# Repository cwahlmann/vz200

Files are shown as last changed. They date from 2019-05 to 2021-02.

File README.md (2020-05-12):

# VZ200
## Nachbau eines VZ200-Color-Computers (1983)

Mit einem funktionstüchtigen Nachbau des "VZ200 Color Computer" von 1983 lassen wir die Welt der 8-Bit Computer wieder auferstehen.

__Autoren:__ Jürgen Wahlmann & Christian Wahlmann



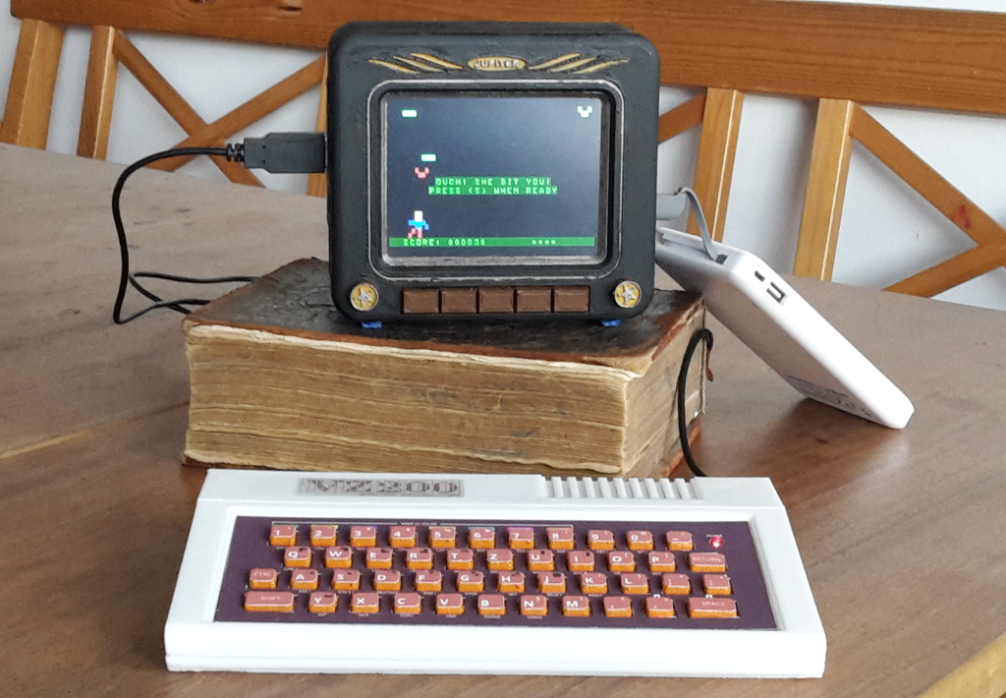
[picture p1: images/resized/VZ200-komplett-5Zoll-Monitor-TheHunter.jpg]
Prototyp VZ200 - 70%


Dieses Repository dient der Verwaltung aller Sourcen, insbesondere
* 3d-Modelle (Fusion360)
* Platinenlayout (KiCad)
* Grafiken für Tastatur- und Logo-Aufkleber
* JemuVZ200-Emulator (Java-8 / Gradle)
* VZ200 Companion App (Angular)

Dokumentation und Releases sind gehostet unter https://cwahlmann.github.io/vz200-remake

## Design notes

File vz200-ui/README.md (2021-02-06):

# VZ200 UI

This is an example project that can be used as a starting point to create your own Vaadin application with Spring Boot.
It contains all the necessary configuration and some placeholder files to get you started.

The project is a standard Maven project, so you can import it to your IDE of choice. [Read more how to set up a development environment](https://vaadin.com/docs/v14/flow/installing/installing-overview.html) for Vaadin projects (Windows, Linux, macOS). 

This project was created from https://start.vaadin.com.

## Running and debugging the applcation

### Running the application from the command line.
To run from the command line, use `mvn` and open http://localhost:8080 in your browser.

### Running and debugging the application in Intellij IDEA
- Locate the Application.java class in the Project view. It is in the src folder, under the main package's root.
- Right click on the Application class
- Select "Debug 'Application.main()'" from the list

After the application has started, you can view your it at http://localhost:8080/ in your browser. 
You can now also attach break points in code for debugging purposes, by clicking next to a line number in any source file.

### Running and debugging the application in Eclipse
- Locate the Application.java class in the Package explorer. It is in `src/main/java`, under the main package.
- Right click on the file and select `Debug As` --> `Java Application`.

Do not worry if the debugger breaks at a `SilentExitException`. This is a Spring Boot feature and happens on every startup.

After the application has started, you can view your it at http://localhost:8080/ in your browser.
You can now also attach break points in code for debugging purposes, by clicking next to a line number in any source file.
## Project structure

- `MainView.java` in `src/main/java` contains the navigation setup. It uses [App Layout](https://vaadin.com/components/vaadin-app-layout).
- `views` package in `src/main/java` contains the server-side Java views of your application.
- `views` folder in `frontend/src/` contains the client-side JavaScript views of your application.

## What next?

[vaadin.com](https://vaadin.com) has lots of material to help you get you started:

- Follow the tutorials in [vaadin.com/tutorials](https://vaadin.com/tutorials). Especially [vaadin.com/tutorials/getting-started-with-flow](https://vaadin.com/tutorials/getting-started-with-flow) is good for getting a grasp of the basic Vaadin concepts.
- Read the documentation in [vaadin.com/docs](https://vaadin.com/docs).
- For a bigger Vaadin application example, check out the Full Stack App starter from [vaadin.com/start](https://vaadin.com/start).

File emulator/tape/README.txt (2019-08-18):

This folder stores various TAPE-folder, that are stored and read 
via the CSAVE, CLOAD and CRUN commands.

TAPE controle is done by http-REST or by the INP() / OUT() functions:

Endpoint     | Method | Request | Response | Description
-------------|--------|---------|----------|-------------
/tape        | GET    |         | String   | Namen des eingelegten Tapes lesen
/tape/{name} | POST   |         | String   | Type mit angegebenem Namen einlegen
/tape/slot   | GET    |         | Integer  | aktuellen Slot des Tapes lesen
/tape/slot/{id} | GET | Integer |          | Tape zu angegebenem Slot spulen
/tape/play   | POST   |         | Integer  | Tape starten; gibt Slot zurück
/tape/record | POST   |         | Integer  | Aufnahme starten; gibt Slot zurück
/tape/stop   | POST   |         | Integer  | Tape stoppen; gibt Slot zurück

PORT | IN / OUT | Description
-----|----------|-------------
254  | OUT      | 0: STOP, 1: PLAY, 16: RECORD
255  | OUT      | REWIND to position [n]
254, 255  | IN  | get LSB / MSB of tape position

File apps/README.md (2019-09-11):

# VZ200 Companion App

This App supports the retro enthusiast while dealing with the VZ200 - Emulator. It allows for doing file transfers and operations on the emulated device as well as organizing files made available to the emulation. 

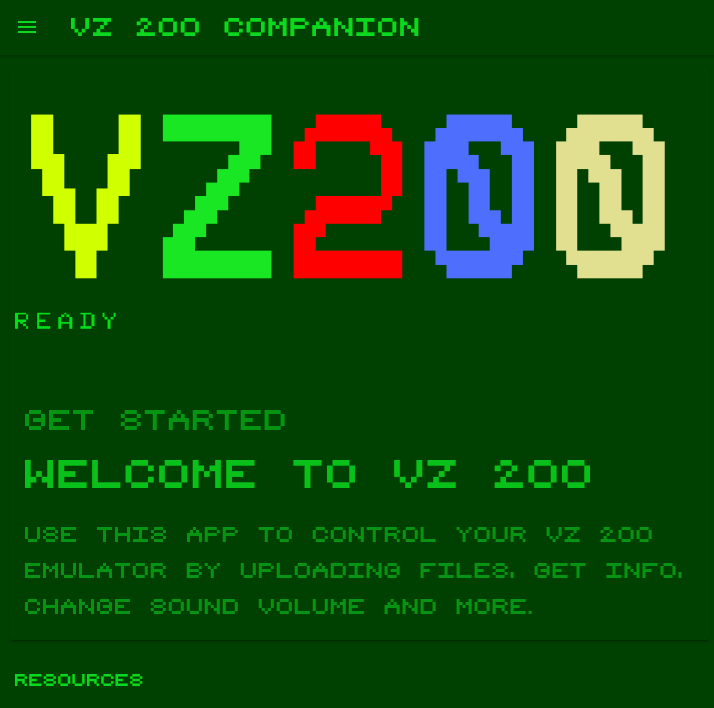
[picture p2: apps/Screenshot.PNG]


## Installation / prerequisites

### Install NPM

Download and install NodeJS from the official site.

https://nodejs.org/en/download/

### Install Ionic

> npm install -g ionic

### Install git

https://git-scm.com/downloads

## Build and run the App

Checkout the App from this repo into a directory of your choice:

> git clone https://github.com/cwahlmann/vz200/new/master/apps/VZ200-App

Install dependencies

> npm i

Run the App

> ionic serve

The App should be available at http://localhost:4200

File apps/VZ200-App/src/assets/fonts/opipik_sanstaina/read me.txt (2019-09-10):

The font file in this archive was created using Fontstruct the free, online
font-building tool.
This font was created by “opipik”.
This font has a homepage where this archive and other versions may be found:
http://fontstruct.com/fontstructions/show/763544

Try Fontstruct at http://fontstruct.com
It’s easy and it’s fun.

NOTE FOR FLASH USERS: Fontstruct fonts (fontstructions) are optimized for Flash.
If the font in this archive is a pixel font, it is best displayed at a font-size
of 16.

Fontstruct is sponsored by FontShop.
Visit them at http://www.fontshop.com
FontShop is the original independent font retailer. We’ve been around since
the dawn of digital type. Whether you need the right font or need to create the
right font from scratch, let our 22 years of experience work for you.

Fontstruct is copyright ©2013 Rob Meek

LEGAL NOTICE:
In using this font you must comply with the licensing terms described in the
file “license.txt” included with this archive.
If you redistribute the font file in this archive, it must be accompanied by all
the other files from this archive, including this one.

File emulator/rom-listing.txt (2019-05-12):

sTART UP SCREEN:

-------------------------------
|VIDEO TECHNOLOGY             |
|BASIC VER 2.0                |
|                             |
|READY                        |
|                             |
|                             |
|                             |
|                             |
|                             |
|                             |
|                             |
-------------------------------

If CTRL is held down while vz is turned on (bootup), background colour goes darkish green, else
is yellow background.

just some quick general info....
----------------------------------

ROM0.DBG     - first 8k bank of 16k BASIC ROM     (00000h to 01FFFh)
ROM1.DBG     - second 8k bank of 16k BASIC ROM    (02000h to 03FFFh)
ROM2.DBG     - 8k bank of DOS BASIC version 2.0   (04000h to 05FFFh)
ROM-FULL.DBG - the above three together.

0000-1FFF ROM 0 8K (VZ-200)
2000-3FFF ROM 1 8K (VZ-200)
0000-3FFF ROM (VZ-300)

4000-5FFF DOS ROM 8K
6000-67FF RESERVED FOR ROM CARTRIDGES (2K)
6800-6FFF MEMORY MAPPED I/O 2K; KEYBOARD, CASSETTE I/O, SPEAKER, VDP CONTROOL
7000-77FF VIDEO RAM 2K
7800-8FFF INTERNAL USER RAM 6K (RESERVED RAM VZ-200)
7800-B7FF INTERNAL USER RAM 16K (RESERVED RAM VZ-300)
9000-CFFF 16K EXPANSION (VZ-200)
B800-F7FF 16K EXPANSION (VZ-300)

5640  5711 Routine pointer table 1
5712  6177 word table
6178  6297 Routine pointer table 2

31465	7AE9	START OF USER MEMORY
36864	9000	TOP OF MEMORY VZ-200 (6K)
45184	B800	TOP OF MEMORY VZ-300 (16K)
53348	D000	TOP OF MEMORY VZ-200 (6K + 16K EXPANSION)
63488	F800	TOP OF MEMORY VZ-300 (16K + 16k EXPANSION)
65535	FFFF	THE VERY TOP

token			routine		address
address	token	word	dec	lo	hi	hex
5712	128	end	7598	174	29	1dae
5715	129	for	7329	161	28	1ca1
5718	130	reset	312	56	1	0138
5723	131	set	309	53	1	0135
5726	132	cls	457	201	1	01c9
5732	134	random	467	211	1	01d3
5738	135	next	8886	182	34	22B6
5742	136	DATA	7941	5	31	1F05
5746	137	INPUT	8602	154	33	219A
5751	138	DIM	9736	8	38	2608
5754	139	READ	8687	239	33	21EF
5758	140	LET	7969	33	31	1F21
5761	141	GOTO	7874	194	30	1EC2
5765	142	RUN	7843	163	30	1EA3
5768	143	IF	8249	57	32	2039
5770	144	RESTORE	7569	145	29	1D91
5777	145	GOSUB	7857	177	30	1EB1
5782	146	RETURN	7902	222	30	1EDE
5788	147	REM	7943	7	31	1F07
5791	148	STOP	7953	169	29	1DA9
5795	149	ELSE	7943	7	31	1F07
5799	150	COPY	14610	18	57	3912
5803	151	COLOR	14493	157	56	389D
5808	152	VERIFY	14136	56	55	3738
5814	153	DEFINT	7683	3	30	1E03
5820	154	DEFSNG	7686	6	30	1E06
5826	155	DEFDBL	7689	9	30	1E09
5832	156	CRUN	14126	46	55	372E
5836	157	MODE	11875	99	46	2E63
5840	158	SOUND	11253	245	43	2BF5
5845	159	RESUME	8111	175	31	1FAF
5851	160	OUT	11003	251	42	2AFB
5854	161	ON	8044	108	31	1F6C
5856	162	OPEN	31097	121	121	7979
5860	163	FIELD	31100	124	121	797C
5865	164	GET	31103	127	121	797F
5868	165	PUT	31106	130	121	7982
5871	166	CLOSE	31109	131	121	7988
5876	167	LOAD	31112	136	121	7988
5880	168	MERGE	31115	139	121	798B
5885	169	NAME	31118	142	121	798E
5889	170	KILL	31121	145	121	7991
5893	171	LSET	31127	151	121	7997
5897	172	RSET	31130	154	121	799A
5901	173	SAVE	31136	160	121	79A0
5905	174	SYSTEM	0	0	0	0000
5911	175	LPRINT	8295	103	32	2067
5917	176	DEF	31067	91	121	795B
5920	177	POKE	11441	177	44	2CB1
5924	178	PRINT	8303	111	32	206F
5929	179	CONT	7652	228	29	1DE4
5933	180	LIST	11054	46	43	2B2E
5937	181	LLIST	11049	41	43	2B29
5942	182	DELETE	11206	198	43	2BC6
5948	183	AUTO	8200	8	32	2008
5952	184	CLEAR	7802	122	30	1E7A
5957	185	CLOAD	13910	86	54	3656
5962	186	CSAVE	13481	169	52	34A9
5967	187	NEW	6985	73	27	1B49
5970	188	TAB(	NO ADDRESS LIST
5974	189	TO	NO ADDRESS LIST
5976	190	FN	NO ADDRESS LIST
597B	191	USING	NO ADDRESS LIST
5983	192	VARPTR	NO ADDRESS LIST
5989	193	USR	NO ADDRESS LIST
5992	194	ERL	NO ADDRESS LIST
5995	195	ERR	NO ADDRESS LIST
5998	196	STRING$	NO ADDRESS LIST
6005	197	INSTR	NO ADDRESS LIST
6010	198	POINT	NO ADDRESS LIST
6015	199	TIME$	NO ADDRESS LIST
6020	200	MEM	NO ADDRESS LIST
6023	201	INKEY$	NO ADDRESS LIST
6029	202	THEN	NO ADDRESS LIST
6033	203	NOT	NO ADDRESS LIST
6036	204	STEP 	NO ADDRESS LIST
6040	205	+	NO ADDRESS LIST
6041	206	-	NO ADDRESS LIST
6042	207	*	NO ADDRESS LIST
6043	208	/	NO ADDRESS LIST
6044	209	^	NO ADDRESS LIST
6045	210	AND	NO ADDRESS LIST
6048	211	OR	NO ADDRESS LIST
6050	212	>	NO ADDRESS LIST
6051	213	=	NO ADDRESS LIST
6052	214	<	NO ADDRESS LIST
6053	215	SGN	2442	138	9	098A
6056	216	INT	2871	55	11	0B37
6059	217	ABS	2423	119	9	0997
6062	218	FRE	10196	212	39	27D4
6065	219	INP	10991	239	42	2AEF
6068	220	POS	10229	245	39	27F5
6071	221	SQR	5095	231	19	13E7
6074	222	RND	5321	201	20	14C9
6077	223	LOG	2057	9	8	0809
6080	224	EXP	5177	57	20	1439 (?)
6083	225	COS	5441	65	21	1541
6086	226	SIN	5447	71	21	1549 (?)
6089	227	TAN	5544	168	21	15AB
6092	228	ATN	5565	189	21	15BD
6095	229	PEEK	11434	170	44	2CAA
6099	230	CVI	31058	82	121	7952
6102	231	CVS	31064	88	121	7954
6105	232	CVD	31070	94	121	795E
6108	233	EOF	31073	97	121	7961
6111	234	LOC	31076	100	121	7964
6114	235	LOF	31079	103	121	7967
6117	236	MKI$	31082	106	121	796A
6121	237	MKS$	31085	109	121	796D
6125	238	MKD$	31088	112	121	7970
6129	239	CINT	2687	127	10	0A7F
6133	240	CSNG	2737	177	10	0AB1
6137	241	CDBL	2779	219	10	0ADB
6141	242	FIX	2854	38	11	0B26
6144	243	LEN	10755	3	42	2A03
6147	244	STR$	10294	54	40	2836
6151	245	VAL	10949	197	42	2AC5
6154	246	ASC	10767	15	42	2A0F
6157	247	CHR$	10783	31	42	2A1F
6161	248	LEFT$	10849	97	42	2A81 (?)
6166	249	RIGHT$	10897	145	42	2A91
6172	250	MID$	10906	154	42	2A9A

Disk tokens and offsets WITH NO ROUTINES AT THESE LOCATIONS (SPARE TOKENS)

word 
address	token	word	address in pointer
5729	133	CMD	31091
5856	162	OPEN	31097
5860	163	FIELD	31100
5865	164	GET	31103
5868	165	PUT	31106
5871	166	CLOSE	31109
5876	167	LOAD	31112
5880	168	MERGE	31115
5885	169	NAME	31118
5889	170	KILL	31121
5893	171	LSET	31127
5897	172	RSET	31130
5901	173	SAVE	31136
5905	174	SYSTEM	0
5917	176	DEF	31067
5976	190	FN	NO ADDRESS LIST
6005	197	INSTR	NO ADDRESS LIST
6015	199	TIME$	NO ADDRESS LIST
6099	230	CVI	31058
6102	231	CVS	31064
6105	232	CVD	31070
6108	233	EOF	31073
6111	234	LOC	31076
6114	235	LOF	31079
6117	236	MKI$	31082
6121	237	MKS$	31085
6125	238	MKD$	31088

Most of the VZs BASIC words that were never enabled in the VZ have dedicated
processing routines in ROM. Each of these words is listed along with its token
code, its start address in the WORD TABLE, and the start address for the 
routine that processes it. The routine addresses are listed in decimal, then
in LO HI format (where address = LO + HI * 256) and in hex.

Words from END (token 128) to NEW (token 187) are all words that must begin
a BASIC statement if they are used at all. Some such as END,CLS,NEW,STOP must
stand alaone as the entire statement or be the primary word of an extended
statement.

Each of these words has a two byte pointer in the POINTER TABLE that follows 
the WORD TABLE. The pointer contains the address (in LO HI format) of the
routine that executes the word.

Words from SGN (token 215) to MID$ (token 250) are all words that cannot 
occur at the start of a basic statement. Each has a pointer in the POINTER
TABLE which proceeds the WORD TABLE, where again the pointer addresses a 
processing routine (execute!) for that word.

Words from TAB( (token 188) to < (token 214) do not have pointers in either of
the POINTER TABLES. They are executed by the primary words of statements in
which they occur. Strictly speaking it is the tokens that do all the dirty
work. 

When the program is RUN, tokens 205 to 208 and 212 to 214 designate words that 
display on screen as graphic characters (sort of like the ZX spectrum had).
The program is accurate. The first byte of each word being in inverse form
to mark the start of a new word. This is strictly true for words which begin
with alphabetical characters, the majority, but not for those few words that
consist of  nonalphabetical characters. A more accurate wording would be:

The first byte of each word being the ASCII character code + 128 to mark the
start of a new word. For alphabetical characters, adding 128 to the ASCII code
will yield the inverse character code. Most BASIC words begin with an 
alphabetical character, so most of the words in the WORD TABLE will begin with
an inverse character. However a few BASIC words consist of a single 
nonalphabetical character:   +,,*,/,^,>,=,<

They too are represented in the WORD TABLE by the ascii code + 128, but this
does not yield the inverse character codes. On the VZ, for those characters
with ASCII codes less than 64, the inverse character code is the ASCII code
+ 192. Still, when the VZ BASIC INTERPRETER comes across one of these words 
in the WORD TABLE, it subtracts 128 to get the ASCII code.

RAM Communication Region

30720 - 30740  	7800-7814	RST JUMP VECTORS

30720-2	7800-2	RST 8  JP 1C96
30723-5 7803-5	RST 10 JP 1D78 (dos 4293)
30726-8 7806-8	RST 18 JP 1C90
30729-31 7809-B RST 20 JP 25D9
30732-4	780C-E	RST 28 SET TO RETURN
30735-7	780F-11	RST 30 SET TO RETURN
30738-40 7812-4	RST 38 SET TO EI,RETURN

30741 - 30748	7815 - 781C	KEYBOARD D.B.C

30741	7815	DEVICE TYPE 1
30742-3	7816	DRIVER ADDRESS 12020
30744	7818	INVERSE SCREEN
30745	7819	INVERSE CHARACTERS
30746	781A	? NOT USED
30747-8	781B-C	RAM BUFFER ADDRESS NOT USED

30749-30756	781D-7824	VIDEO D.B.C

30749	781D	DEVICE TYPE 0
30750-1	781E-F	DRIVER ADDRESS
30752-3	7820-1	CURSOR POSITION RANGE 28672 TO 29183
30754	7822	? NOT USED
30755-6	7823-4	CHECKSUM DURING TAPE LOAD

30757 - 30764	7825 - 782C	PRINTER D.B.C
30757	7825	DEVICE TYPE 6
30758-9	7826-7	DRIVER ADDRESS 1421
30760	7828	LINES PER PAGE ? NOT USED
30761	7829	LINES PRINTED SO FAR ? NOT USED
30762	782A	?NOT USED
30763-4	782B-C	RAM BUFFER ADDRESS ? NOT USED

30765-70 782D-32 ?UNUSED BY VZ
30771-3	7833-5	LD A,0 RET	PRINTER ERROR VECTOR
30774	7836	START OF KEYBOARD WORK AREA
		STORE FOR CHARACTER OF KEY PRESSED
30775	7837	?
30776	7838	INVERSE PRINTING 2 enables
30777	7839	LOW RES SPEED UP 35 is slow
		BIT 3 - VERIFY FLAG (LOADING ROUTINE)
		BIT 4 - UP/DOWN CURSOR DISABLE
		BIT 5 - AUTORUN (CRUN) FLAG
30778	783A	?
30779	783B	COPY OF O/P LATCH / BACKGROUND COLOUR; 32 GREEN
		48 buff
30780	783C	STORES CHARACTERS AT CURSOR POSITION
30781	783D	VIDEO CONTROL WORD ? NOT USED
30782-844	783E-7C	USED DURING IPL SEQUENCE - when computer first 
		switched on
30785	7841	CURSOR FLASH RATE
30786-89	USED IN KEYBOARD SCAN ROUTINE
30786		STORES ROW NUMBER OF KEYBOARD ; range 1-8
30787		STORES COLUMN NUMBER OF KEYBOARD ; range 1-6
30788-9		STORES THE ROW ADDRESS
30790		STORES FOREGROUND COLOUR; 0,16,32,48,64,80,96,112
		-colours green to orange
30796		LOADING MESSAGE DISABLE FLAG (nonzero=disable)
30845-7		INTERRUPT EXIT
30848-61	DIVISION SUPPORT ROUTINE
30862-3		USR POINTER
30864		RND NUMBER SEED
30867-9		IN A,0 RET	INP ROUTINE
30870-2		OUT (O),A RET	OUT ROUTINE
30873		LAST KEY PRESSED
30874		ERROR CODE STORAGE/SIGNALS RESUME ENTERED
30875		PRINTER CARRIAGE POSITION
30876		OUTUT DEVICE CODE 0=video,1=printer,255(-1)=cassette
30877		SIZE OF VIDEO LINE ?NOT USED
30878		HIGH OR LOW RES?NOT USED
30879		?NOT USED
30880-1		BASIC STACK ADDRESS/LOWER BOUNDARY OF STRING SPACE
30882-3		CURRENT BASIC LINE NUMBER/ADDRESS OF LINE WITH ERROR
30884-5		START OF PROGRAM
30886		TAB CURSOR POSITION
30887-8		KEYBOARD BUFFER POINTER;31208
30889		0 IF CASSETTE INPUT ELSE NONZERO
30890-3		RANDOM NUMBER SEED
30894		VARIABLE FLAG
30895		VARIABLE TYPE FLAG (integer,string,single,double)
30896		EXPRESSION EVALUATION/DATA STATEMENT FLAG
30897-8		TOP OF MEMORY  POINTER
30899-900	NEXT LOCATION IN LITERAL STRING POOL
30901-30	LITERAL STRING POOL; 30bytes
30931		LENGTH OF LAST DEFINED STRING
30932-3		ADDRESS OF LAST DEFINED STRING
30934-5		POINTER TO NEXT AVAILABLE PLACE IN STRING SPACE
30936-7		INDEX OF LAST BYTE EXECUTED IN CURRENT STATEMENT EDIT FLAG
		DURING PRINT USING
30938-9		LINE NUMBER OF LAST DATA STATEMENT READ
30940		'FOR' STATEMENT FLAG; 1 FOR IN PROGRESS; 0 NO FOR
30941		INPUT PHRASE ENTERED FLAG; 0 DURING INPUT PHASE
30942		INPUT/READ FLAG; 0 INPUT; 1 READ
30943-4		POINTER TO START OF PROGRAM WHEN RUN
30945		AUTO INPUT FLAG FIELD; 0=no auto
30946-7		CURRENT LINE NUMBER DURING INPUT PHASE
30948-9		AUTOLINE INCREMENR
30950-1		ADDRESS OF LAST BYTE EXECUTED IN CURRENT LINE
30952-3		BACKSPACED STACK ADDRESS
30954-5		ERROR LINE NUMBER
30956-7		ERROR LINE NUMBER / LINE NUMBER FOR LAST BASIC LINE ENTERED OR
		DELETED
30958-68	?
30969-70	END OF PROGRAM/START SIMPLE VARIABLES TABLE
30971-2		START OF DIM VARIABLES TABLE
30973-4		START OF FREE MEMORY
30975-6		DATA POINTER (read statement)
30977-1002	VARIABLE DECLARATION TABLE 26 entries (A to Z)
31003		TRACE FLAG 1=on 0=off
31004		TEMPORARY STORAGE USED BY NUBERIC ROUTINES WHEN UNPACKING A 
		FLOATING POINT NUMBER
31005-31012	WORKING REGISTER AREA 

	INTERGER SINGLE DOUBLE,

31005			LSB
31006			LSB
31007			LSB
31008			LSB
31009	LSB	LSB	LSB	;31009-10 USER ARGUMENT STORE
31010	MSB	LSB	LSB
31011		MSB	MSB
31012		EXP	EXP

31013		SIGN OF RESULT DURING MATH & ARITHMETIC OPERATIONS
31014		BIT BUCKET USED DURING DP ADDITION
31015-22	WRA2 SAME AS WRA1
31023		not used
31024-49	PRINTER BUFFER
31050-7		TEMPORAY STORAGE USED BY DOUBLE PRECISION DIVISION ROUTINE
31058-147	TRS-80 DISK BASIC EXITS - INITIALISED TO RETURNS

31148-204 	79AC-79E4 	TRS-80 DOS EXIT ADDRESSES
31148		79AC		DOS EXIT FROM:  1A1C
		79AF
		79B2				1AA1	
		79B5				1AEC
		79B8				1AF2
		79BB				1B8C
		79BE				2174
		79C1				032C
		79C4				0358
		79C7				1EA6
		79CA				206F
		79CD
		79D0				2103
		79D3				2108
		79D6				219E
		79DC				222D
		79DF				2278
		79E2

31205-7		USED BY INPUT
31208-72	BASIC LINE INPUT BUFFER
31273		116 BYTES OF UNUSED MEMORY
31389		TAPE NAME
31405-31446	?
31447-31462	TAPE LOADING ROUTINE
31463-4		ZERO

End of Communications RAM Region
-----------------------------------------------------------------------------

DOS ENTRY POINTS
a jump table to the dos subroutines is positioned at the fixed
address from 4008h to 4044h. the jump table contains the following elements:

4008h	jp pwrin 	disk power on
400bh	jp pwoff	disk power off
400eh	jp error	error handling routine
4011	jp rdmap	read the track map of the disk
4014	jp clear	clear a sector of the disk
4017	jp svmap	save the track map to the disk
401a	jp init		initialises the disk
401d	jp csi		command string interpreter
4020	jp hex		convert ascii to hex
4023	jp idam		read the identification address mark
4026	jp create 	create an entry in directory
4029	jp map		search for empty sector
402c	jp search	search for file in directory
402f	jp find		search empty space in directory
4032	jp write	write a sector to disk
4035	jp read		read a sector from disk
4038	jp dly		delay ms in reg c
403b	jp stpin	step in
403e	jp stpout	step out
4041	jp dkload	load a file from disk
4044	jp saveob	save a file to disk

# = HEX
$ = DECIMAL

-------+-----------------------+---------
DECIMAL|Z80 OPCODE	       |COMMENTS	
LINE # |                       |
-------+-----------------------+---------

0	DI			INTERRUPTS DISABLED
1	XOR 	A		ZERO THE ACCUMULATOR
2	LD	(#6800), A	RAM LOCATION #6800 = 26624; IS ZEROED
5	JP	#0674		#674=1652; JMP TO CONTINUE IPL SEQUENCE

1652	NOP
1653	NOP
1654	LD	HL, #06D2	SET UP COPYING ROM FROM #06D2
1657	LD	DE, #7800	TO RAM COMMUNICATIONS AREA #7800=30720
1660	LD	BC, #0036	OF 54 BYTES
1663	LDIR
1665	DEC	A		A = 255 WHEN DECREMENTED 
1666	DEC	A		FROM ZERO:DECREMENT TWICE
1667	JR	NZ,$ -15	JUMP TO 1654 AND REPEAT COPY IF REGISTER
				A NOT 0
1669	LD	B,#27		COPY REPEATED 128 TIMES. 39 LOCATIONS FROM #7836 WILL BE
1671	LD	(DE), A		ZEROED IN COMMS REGION.
1672	INC	DE
1673	DJNZ	$ -4		JUMP TO 1671. ZERO #7836 TO #785C
1675	JP	#0075		#0075=117; JUMP AND CONTINUE IPL SEQUENCE

117	LD	DE, #7880	#7880=30848: START LOC IN COMMS REGION FOR ANOTHER COPY
120	LD	HL,#18F7	FROM ROM AT #18F7 = 6391
123	LD	BC, #0027	OF 39 BYTES: WILL COPY INITIALISATION DATA IN ROM FROM #18F7 TO #191D
126	LDIR			TO COMMS REGION #7880 TO #78A6
128	LD	HL, #79E5	CONTINUE INIT OF COMS REGION. #79E5 = 31205
131	LD	(HL),#3A	PUT ASCII CODE FOR COLON IN LOCATION 31205
133	INC	HL		HL=31206
134	LD	(HL),B		PUT ZERO IN 31206
135	INC	HL
136	LD	(HL), #2C	PUT ASCII CODE FOR COMMA IN LOCA. 31207
138	INC	HL		HL=31208
139	LD	(#78A7), HL	#78A7=30887: KEBOARD BUFFER POINTER SET TO START OF INPUT BUFFER
142	LD	DE, #012D	#012D=301: IS ADDRESS FIELD FOR JP #12D, 28 JUMPS WILL BE SETUP
145	LD	B, #1C		IN COMMS REGION FROM 31058 TO 31131: JUMPS TO ERROR MESSAGE IF 
147	LD	HL, #7952	DISK COMMAND TOKENS USED #7952 = 31058: IS START OF DISK BASIC
150	LD	(HL), #C3	IN COMMS REGION. #C3 = 195 IS MACHINE CODE FOR UNCONDITIONAL JMP
152	INC	HL		
153	LD	(HL), E		FOR UNCONDITIONAL JUMP
154	INC	HL
155	LD	(HL),D
156	INC	HL
157	DJNZ	$ -9		JMP TO 150, LOOP 28 TIMES
159	LD	B, #15		21: LOOP COUNT FOR TRS-80 DOS EXIT RETURNS
161	LD	(HL), #C9	STARTING AT 31142, INITIALISE 21 RETURNS
163	INC	HL		THE FIRST TWO RETURNS ARE FOR DISK BASIC EXITS
164	INC	HL		
165	INC	HL		DOS EXIT RETURNS BEGIN AT 31148
166	DJNZ	$ -7		JMP TO 161: LOOP 21 TIMES
168	LD	HL, #7AE8	#7AE8 = 31464: IS LAST LOCATION IN COM REGION. ZERO THIS LOC
171	LD	(HL), B		BECAUSE BASIC PROGRAMS REQUIRE 0 START TO RUN DURING IPL SEQ.
172	LD	SP, #79F8	#79F8=31224: IS TEMP START OF STACK
175	CALL	#1B8F		#1B8F=7055: INITIALISE BASIC POINTERS/VARIABLES
178	CALL	#01C9		#01C9=457: TO CLEAR THE SCREEN
181	NOP			These nop instructions were the location of a trs-80 user input
182	NOP			memory size routine that has been removed from the vz o/s
183	NOP
184	NOP
185	NOP
186	NOP
187	NOP
188	NOP
189	NOP
190	JR	$ +4		JUMP TO 196
192	RST			NOT PART OF VZ IPL
193	OR	A		NOT PART OF VZ IPL
194	JR	NZ, $ +18	NOT PART OF VZ IPL
196	LD	HL, #7B4C	#7B4C=31564: SETTING UP FOR A ROUTINE TO DETERMINE MEM. SIZE
199	INC	HL		STARTING AT 31565 IN RAM AND WORKING TOWARD 65535 (MAX 
200	LD	A, H		ADDRESSABLE MEM FOR VZ), TESTING FOR PRESENCE OF RAM
201	OR	L		
202	JR	Z, $ +27
204	LD	A, (HL)		GET BYTE AT CURRENT LOCATION
205	LD	B, A		BEING TESTED AND SAVE IT
206	CPL			COMPLEMENT IT & WRITE NEW
207	LD	(HL), A		BYTE TO TEST LOCATION
208	CP	(HL)		CHECK IF WRITE SUCCEEDED
209	LD	(HL), B		RESTORE ORIGINAL BYTE
210	JR	Z, $ -13	IF TEST LOCATION EXISTS, JUMP TO 199 & TEST NEXT
212	JR	$ +17		JUMP TO 231 BECAUSE CURRENT TEST LOC, ABSENT

231	DEC	HL		WE HAVE TOP OF RAM
232	LD	DE, #7C14	#7C14=31764: USE THIS AS MINIMUM REQUIRED RAM AND GO TEST THAT 
235	RST	#18		MINIMUM RAM NOT LESS THAN 31764
236	JP	C, #197A	#197A = 6522: JUMP TO INSUFFICIENT MEMORY ROUTINE IF MINIMUM RAM 
239	LD	DE, #FFCE	LESS ELSE CONTINUE IPL. #FFCE=65486: - DEFAULT SIZE (50) FOR
242	LD	(#78B1), HL	STRING SPACE (65536 - 50). #78B1=30897: SET TOP OF RAM POINTER
245	ADD	HL, DE
246	LD	(#78A0), HL	#78A0=30880: SET LOWER BOUNDARY OF STRING SPACE IN POINTER 30880/1
249	CALL	#1B4D		#1B4D = 6989: GO AND INITIALISE ALL BASIC POINTERS AND VARIABLES
252	CALL	#3484		#3484=13444: SEE DISASSEMBLY AT END OF LISTING
255	LD	HL, #010F	#010F=271: IS START OF "VIDEO TECHNOLOGY" MESSAGE
258	CALL	#28A7		#28A7=10407: TO MESSAGE OUTPUT ROUTINE
261	IM	1		SET INTERRUPT MODE 1 CONDITION - A RST #38 EXECUTES IF AN INT OCCURS
263	JP	#068E		CONTINUE IPL SEQUNCE FROM #68E

1678	LD	HL, #4000	#4000 = 16384 IS START OF DOS RAM ROM IF DISK DRIVE CONNECTED
1681	CALL	#06A4		GO AND CHECK FOR PRESENCE OF DOS BY TESTING IDENTITY OF FIRST
				FOUR BYTES FROM 1638. IF TEST REVEALS PRESENCE OF DOS, THE 
				CHECKING SUBROUTINE WILL NOT RETURN INSTEAD, A JUMP TO DOS IPL
				SEQUENCE WILL BE EXECUTED
1684	LD	HL, #6000	NO DOS, SO RETURN HERE. #6000=24576 IS START OF THE 2K LOCATED
				ABOVE DOS RAM
1687	CALL	#06A4		GO AND CHECK FOR PRESENCE OF FORU IDENTITY BYTES FROM 24576
				IF ALL BYTES FOUND THEN CHECKING ROUTINE WILL NOT RETURN
				INSTEAD A JUMP TO 24580 WILL BE EXECUTED
1690	LD	HL, #8000	#8000=32768 IS USUALLY AN ADDRESS IN PROGRAM (RAM) MEMORY
1693	CALL	#06A4		GO AND CHECK FOR PRENCE OF FOUR IDENTITY BYTES FROM 32768
				UNLESS ROM OR EPROM HAS BEEN INSTALLED FROM 32768 WITH THE FOUR
				ID BYTES, THE TEST WILL FAIL AND CHECKING SUBROUTINE WILL RETURN
				TO HE CALLER
1696	EI			INTERRUPTS WILL BE ENABLED
1697	JP	#1A19		AND THE IPL SEQUENCE WILL END WITH A JUMP TO READY ROUTINE
				THE VZ IS SET UP FOR USE.

----------------------------------------------------------

Test routine for presence of code sequence - four bytes.

#6A4	1700	LD	A, #AA		170 IS THE FIRST TEST BYTE
	1702	CP	(HL)		IS BYTE AT ADDRESS IN HL REGISTER = 170?
	1703	INC	HL		NEXT ADDRESS
	1704	RET 	NZ		RETURN IF <> 170
	1705		CPL			ELSE COMPLEMENT BYTE IN ACCUMULATOR
	1706	CP 	(HL)		IS BYTE AT SECOND ADDRESS IN HL REG = NEW BYTE IN ACCUMULATOR?
	1707	INC	HL		NEXT ADDRESS
	1708	RET	NZ		RETURN IF HL <> ACCUMULATOR
	1709	LD	A, #E7		231 IS THE THIRD TEST BYTE
	1711	CP	(HL)		IS BYTE = 231?
	1712	INC	HL
	1713	RET	NZ		RETURN IF HL <> 231
	1714	CPL			COMPLEMENT
	1715	CP	(HL)		HL := A
	1716	INC	HL
	1717	RET	NZ		RETURN IF HL <> A
	1718	EI			ENABLE INTERUPTS
	1719	JP	(HL)		AND JMP TO ADDRESS IN HL REGISTERS - THE IPL SEQUENCE IS TERMINATED

---------------------------------------------------------

CALLED FROM #F9 IN IPL
#1B4D	6989	LD	HL, (#78A4)	;30884. GET START OF PROGRAM FROM COM REGION POINTER
	6992	CALL	#1DF8		#1DF2=7672: TO TURN TRACE OFF
	6995	LD	(#78E1), A	#78E1=30945: ZERO THE AUTO INPUT FLAG - NO AUTO
	6998	LD	(HL), A		ZERO THE FIRST TWO CELLS OF PROGRAM MEMORY; 31465-466
	6999	INC	HL
	7000	LD	(HL), A
	7001	INC	HL		SET POINTER TO START OF VARIBLE LIST TABLE #78F9=30969 TO 31467
	7002	LD	(#78F9), HL	AS END OF PROGRAM 
	7005	LD	HL, (#78A4)	RECOVER START OF (NULL) PROGRAM FROM POINTER #78A4=30884
	7008	DEC	HL		BACKSPACE TO 31464--LAST
	7009	LD	(#78DF), HL	LOCATION IN COM REGION #78DF/E0 IS POINTER TO PROGRAM START WHEN RUN
	7012	LD	B, #1A		LOAD 26 CELLS IN COM REGION FOR VARIABLE DECLARATION
	7014	LD	HL, #7901	TABLE, STARTING AT #7901=30977: WITH '4' CODE FOR SINGLE PRECISION
	7017	LD	(HL), #04	VARIABLE DECLARATION TABLE
	7019	INC	HL		ONE ENTRY FOR EACH ALPHA CHARACTER
	7020	DJNZ	$ -5		LOOP UNTIL JUMP TO 7017 TABLE DONE
	7022	XOR	A		ZERO ACCUM.
	7023	LD	(#78F2), A	#78F2=30962; FLAG NO ERROR FOR RESUME
	7026	LD	L, A		ZERO
	7027	LD	H, A		HL REGISTERS
	7028	LD	(#78F0), HL	#78F0=30960. ZERO ON ERROR ADDRESS IN #78F0/F1 OF COM REGION
	7031	LD	(#78F7), HL	#78F7=30967: ZERO POINTER TO NEXT STATEMENT FOLLOWING BREAK, STOP, END
	7034	LD	HL, (#78B1)	GET TOP OF MEMORY
	7037	LD	(#78D6), HL	#78D6 = 30934; LOAD POINTER TO NEXT AVAILABLE PLACE IN STRING SPACE
	7040	CALL	#1D91		#1D91=7569; CALL RESTORE ROUTINE TO PUT 31464 IN DATA POINTERS
	7043	LD	HL, (#78F9)	30969; GET END OF BASIC PROGRAM, PREVIOUSLY SET TO 31467
	7046	LD	(#78FB), HL	30971; SET END; SIMPLE VARIABLES POINTER EQUAL TO END OF PROGRAM
	7049	LD	(#78FD), HL	30973; LIKEWISE WITH END OF ARRAY VARIABLES POINTER

----------------------------------------------------------
CALL FROM #FC IN IPL

#3484	13444	CALL	#3FA0		16288; CHECK IF CTRL KEY WAS HELD DOWN WHEN VZ WAS SWITCHED ON
	13447	LD	A, #20		32 IS GREEN SCREEN CODE
	13449	LD	(#7B3B), A	30779; LOAD GREEN SCREEN CODE IN TO 30779
	13452	LD	(#6800), A	ALSO LOAD '32' INTO #6800=26624
	13455		LD	A, #3C
	13457	LD	(#783A), A	30778; LOAD WITH '60'
	13460	LD	A, #10		16 IS CURSOR FLASH COUNT
	13462	LD	(#7841), A	30785; PUT COUNT IN CURSOR FLASH COUNTER. RANGE 16 TO 1
	13465	XOR	A		ZERO ACCUM
	13466	LD	(#7AAF), A	31407; ZERO THIS LOCATION IN COM. REGION.
	13469	LD	HL, #7AB2	31410
	13472		LD	(#7AB0), HL	31408; LOAD 31410 INTO 31408/409
	13475	LD	A, #C9
	13477	JP	#3E37

-----------------------------------------------------

FROM 13477

#3E37 	15927	LD	(#787D), A	30845; LOAD THE INTERRUPT EXIT IN THE COM REGION WITH RET CODE
	15930	LD	A, #10		16 IS CODE FOR YELLOW
	15932	LD	(#7846), A	30790; PUT YELLOW CODE IN GRAPHIC CHARACTER COLOR STORE
	15935	RET			RETURN TO #FF

--------------------------------------------------------

FROM #1B50

#1DF8	7672	XOR	A		ZERO ACCUM
	7673	LD	(#791B), A	31003; SET TRACE FLAG IN COM REGION TO OFF -- TROFF
	7676	RET			RETURN TO #1BF3

---------------------------------------------------------

#1B8C	7052	CALL	#79BB		31163; DOS EXIT IN COMMS REGION, IPL INITIALISED TO RET
	7055	POP	BC		NO PREVIOUS PUSH
	7056	LD	(HL), #7B80	30880; GET LOWER BOUNDARY OF STRING SPACE
	7059	DEC	HL		DECREMENT TWICE AND PUT RESULT IN BACKSPACED STACK ADDRESS STORE
	7060	DEC	HL
	7061	LD	(#78EB), HL	30952
	7064	INC	HL		
	7065	INC	HL
	7066	LD	SP, HL		INC TWICE TO RESTORE ORIGINAL AND PUT INTO Z80 SP REG.
	7067	LD	HL, #78B5
	7070	LD	(#78B3), HL	30899; THEN PUT IN POINTER TO LITERAL STRING POOL; INITIALISED
	7073	CALL	#038B		907; TO SET OUTPUT DEVICE TO VIDEO
	7076	CALL	#2169		8553; ALSO SETS OUTPUT DEVICE TO VIDEO SOME REDUNDANCY HERE
	7079	XOR	A		ZERO ACCUM
	7080	LD	H, A		THEN ZERO
	7081	LD	L, A		HL REGISTERS
	7082	LD	(#78DC), A	30940; ZERO 'FOR' STATEMENT FLAG
	7085	PUSH	HL
	7086	PUSH	BC
	7087	LD	HL, (#78DF)	30943; GET START ADDRESS OF PROGRAM WHEN RUN (31464)
	7090	RET			RETURN TO #FC

-------------------------------------------------------
CALLED FROM #3484: SUBROUTINETO CHECK IF <CTRL> WAS PRESSED WHEN VZ SWITCHED ON

#3FA0	16288	LD	A, (#68FD)	26877; GET BYTE FROM ROM ADDRESS NI KEYBOARD MATRIX THAT
					INCLUDES CTRL KEY
	16291	BIT	2, A		CHECK FOR PRESS OF <CTRL> WHILE VZ IS BEING SWITCHED ON
	16293	LD	A, #20		LOAD ACCUM WITH DARK SPACE CHARACTERS CODE -- DARK CHARACTER FOR LIGHT SCREEN
					THIS IS A PEEK/POKE CODE
	16295	JR	NZ, $ +8	JMP TO 16305 IF <CTRL> IS NOT BEING PRESSED. BIT 2 OF 26877
					WIL BE ZERO IF <CTRL> IS PRESSED
	16297	OR	#40		<CTRL> PRESSED SO CHANGE TO '96' WHICH IS LIGHT SPACE CHARACTER CODE
					AND DARK SCREEN CODE
	16299	LD	(#7818), A	30744; LOCATIONS 30744/45 IN COMMS REGION WERE INITIALLY LOADED WITH ZERO
					BYTES AT START IF IPL SEQUENCE. CHANGE SCREEN FLAG TO DARK, SNICE <CTRL> WAS PRESSED
	16302	LD	(#7819), A	30745; CHANGE SCREEN CHARACTER FLAG TO LIGHT -- LIGHT CHARACTERS ON DARK SCREEN
	16305	LD	(#783C), A	...AND LOAD CURSOR CHARACTER STORE IN COMMS REGION WITH
					SPACE CHARACTER CODE #383C = 30780
	16308	JP	#01C9		457; JUMP TO ROUTINE TO CLEAR SCREEN, HOME CURSOR, AND SELECT MODE(0) (TEXT MODE)

----------------------------------------------------------

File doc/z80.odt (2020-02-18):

# Z80 INSTRUCTION SET:

Instruction T(Z80) Opcode Size

ADC A,(HL) 7 2 8E 1

ADC A,(IX+o) 19 5 DD 8E oo 3

ADC A,(IY+o) 19 5 FD 8E oo 3

ADC A,n 7 2 CE nn 2

ADC A,r 4 1 88+r 1

ADC A,IXp 8 2 DD 88+p 2

ADC A,IYq 8 2 FD 88+q 2

ADC HL,BC 15 2 ED 4A 2

ADC HL,DE 15 2 ED 5A 2

ADC HL,HL 15 2 ED 6A 2

ADC HL,SP 15 2 ED 7A 2

ADD A,(HL) 7 2 86 1

ADD A,(IX+o) 19 5 DD 86 oo 3

ADD A,(IY+o) 19 5 FD 86 oo 3

ADD A,n 7 2 C6 nn 2

ADD A,r 4 1 80+r 1

ADD A,IXp 8 2 DD 80+p 2

ADD A,IYq 8 2 FD 80+q 2

ADD HL,BC 11 1 09 1

ADD HL,DE 11 1 19 1

ADD HL,HL 11 1 29 1

ADD HL,SP 11 1 39 1

ADD IX,BC 15 2 DD 09 2

ADD IX,DE 15 2 DD 19 2

ADD IX,IX 15 2 DD 29 2

ADD IX,SP 15 2 DD 39 2

ADD IY,BC 15 2 FD 09 2

ADD IY,DE 15 2 FD 19 2

ADD IY,IY 15 2 FD 29 2

ADD IY,SP 15 2 FD 39 2

AND (HL) 7 2 A6 1

AND (IX+o) 19 5 DD A6 oo 3

AND (IY+o) 19 5 FD A6 oo 3

AND n 7 2 E6 nn 2

AND r 4 1 A0+r 1

AND IXp 8 2 DD A0+p 2

AND IYq 8 2 FD A0+q 2

BIT b,(HL) 12 3 CB 46+8*b 2

BIT b,(IX+o) 20 5 DD CB oo 46+8*b 4

BIT b,(IY+o) 20 5 FD CB oo 46+8*b 4

BIT b,r 8 2 CB 40+8*b+r 2

CALL nn 17 5 CD nn nn 3

CALL C,nn 17/10 5/3 DC nn nn 3

CALL M,nn 17/10 5/3 FC nn nn 3

CALL NC,nn 17/10 5/3 D4 nn nn 3

CALL NZ,nn 17/10 5/3 C4 nn nn 3

CALL P,nn 17/10 5/3 F4 nn nn 3

CALL PE,nn 17/10 5/3 EC nn nn 3

CALL PO,nn 17/10 5/3 E4 nn nn 3

CALL Z,nn 17/10 5/3 CC nn nn 3

CCF 4 1 3F 1

CP (HL) 7 2 BE 1

CP (IX+o) 19 5 DD BE oo 3

CP (IY+o) 19 5 FD BE oo 3

CP n 7 2 FE nn 2

CP r 4 1 B8+r 1

CP IXp 8 2 DD B8+p 2

CP IYq 8 2 FD B8+q 2

CPD 16 4 ED A9 2

CPDR 21/16 4 ED B9 2

CPI 16 4 ED A1 2

CPIR 21/16 4 ED B1 2

CPL 4 1 2F 1

DAA 4 1 27 1

DEC (HL) 11 4 35 1

DEC (IX+o) 23 7 DD 35 oo 3

DEC (IY+o) 23 7 FD 35 oo 3

DEC A 4 1 3D 1

DEC B 4 1 05 1

DEC BC 6 1 0B 1

DEC C 4 1 0D 1

DEC D 4 1 15 1

DEC DE 6 1 1B 1

DEC E 4 1 1D 1

DEC H 4 1 25 1

DEC HL 6 1 2B 1

DEC IX 10 2 DD 2B 2

DEC IY 10 2 FD 2B 2

DEC IXp 8 2 DD 05+8*p 2

DEC IYq 8 2 FD 05+8*q 2

DEC L 4 1 2D 2

DEC SP 6 1 3B 1

DI 4 2 F3 1

DJNZ o 13/8 2 10 oo 2

EI 4 1 FB 1

EX (SP),HL 19 5 E3 1

EX (SP),IX 23 6 DD E3 2

EX (SP),IY 23 6 FD E3 2

EX AF,AF' 4 1 08 1

EX DE,HL 4 1 EB 1

EXX 4 1 D9 1

HALT 4 2 76 1

IM 0 8 3 ED 46 2

IM 1 8 3 ED 56 2

IM 2 8 3 ED 5E 2

IN A,(C) 12 3 ED 78 2

IN A,(n) 11 3 DB nn 2

IN B,(C) 12 3 ED 40 2

IN C,(C) 12 3 ED 48 2

IN D,(C) 12 3 ED 50 2

IN E,(C) 12 3 ED 58 2

IN H,(C) 12 3 ED 60 2

IN L,(C) 12 3 ED 68 2

IN F,(C) 12 3 ED 70 3

INC (HL) 11 4 34 1

INC (IX+o) 23 7 DD 34 oo 3

INC (IY+o) 23 7 FD 34 oo 3

INC A 4 1 3C 1

INC B 4 1 04 1

INC BC 6 1 03 1

INC C 4 1 0C 1

INC D 4 1 14 1

INC DE 6 1 13 1

INC E 4 1 1C 1

INC H 4 1 24 1

INC HL 6 1 23 1

INC IX 10 2 DD 23 2

INC IY 10 2 FD 23 2

INC IXp 8 2 DD 04+8*p 2

INC IYq 8 2 FD 04+8*q 2

INC L 4 1 2C 1

INC SP 6 1 33 1

IND 16 4 ED AA 2

INDR 21/16 4/3 ED BA 2

INI 16 4 ED A2 2

INIR 21/16 4/3 ED B2 2

JP nn 10 3 C3 nn nn 3

JP (HL) 4 1 E9 1

JP (IX) 8 2 DD E9 2

JP (IY) 8 2 FD E9 2

JP C,nn 10 3 DA nn nn 3

JP M,nn 10 3 FA nn nn 3

JP NC,nn 10 3 D2 nn nn 3

JP NZ,nn 10 3 C2 nn nn 3

JP P,nn 10 3 F2 nn nn 3

JP PE,nn 10 3 EA nn nn 3

JP PO,nn 10 3 E2 nn nn 3

JP Z,nn 10 3 CA nn nn 3

JR o 12 3 18 oo 2

JR C,o 12/7 3/2 38 oo 2

JR NC,o 12/7 3/2 30 oo 2

JR NZ,o 12/7 3/2 20 oo 2

JR Z,o 12/7 3/2 28 oo 2

LD (BC),A 7 2 02 1

LD (DE),A 7 2 12 1

LD (HL),n 10 3 36 nn 2

LD (HL),r 7 2 70+r 1

LD (IX+o),n 19 5 DD 36 oo nn 4

LD (IX+o),r 19 5 DD 70+r oo 3

LD (IY+o),n 19 5 FD 36 oo nn 4

LD (IY+o),r 19 5 FD 70+r oo 3

LD (nn),A 13 4 32 nn nn 3

LD (nn),BC 20 6 ED 43 nn nn 4

LD (nn),DE 20 6 ED 53 nn nn 4

LD (nn),HL 16 5 22 nn nn 3

LD (nn),IX 20 6 DD 22 nn nn 4

LD (nn),IY 20 6 FD 22 nn nn 4

LD (nn),SP 20 6 ED 73 nn nn 4

LD A,(BC) 7 2 0A 1

LD A,(DE) 7 2 1A 1

LD A,(HL) 7 2 7E 1

LD A,(IX+o) 19 5 DD 7E oo 3

LD A,(IY+o) 19 1 FD 7E oo 3

LD A,(nn) 13 4 3A nn nn 3

LD A,n 7 2 3E nn 2

LD A,r 4 1 78+r 1

LD A,IXp 8 2 DD 78+p 2

LD A,IYq 8 2 FD 78+q 2

LD A,I 9 2 ED 57 2

LD A,R 9 2 ED 5F 2

LD B,(HL) 7 2 46 1

LD B,(IX+o) 19 5 DD 46 oo 3

LD B,(IY+o) 19 5 FD 46 oo 3

LD B,n 7 2 06 nn 2

LD B,r 4 1 40+r 1

LD B,IXp 8 2 DD 40+p 2

LD B,IYq 8 2 FD 40+q 2

LD BC,(nn) 20 6 ED 4B nn nn 4

LD BC,nn 10 3 01 nn nn 3

LD C,(HL) 7 2 4E 1

LD C,(IX+o) 19 5 DD 4E oo 3

LD C,(IY+o) 19 5 FD 4E oo 3

LD C,n 7 2 0E nn 2

LD C,r 4 1 48+r 1

LD C,IXp 8 2 DD 48+p 2

LD C,IYq 8 2 FD 48+q 2

LD D,(HL) 7 2 56 1

LD D,(IX+o) 19 5 DD 56 oo 3

LD D,(IY+o) 19 5 FD 56 oo 3

LD D,n 7 2 16 nn 2

LD D,r 4 1 50+r 1

LD D,IXp 8 2 DD 50+p 2

LD D,IYq 8 2 FD 50+q 2

LD DE,(nn) 20 6 ED 5B nn nn 4

LD DE,nn 10 3 11 nn nn 3

LD E,(HL) 7 2 5E 1

LD E,(IX+o) 19 5 DD 5E oo 3

LD E,(IY+o) 19 5 FD 5E oo 3

LD E,n 7 2 1E nn 2

LD E,r 4 1 58+r 1

LD E,IXp 8 2 DD 58+p 2

LD E,IYq 8 2 FD 58+q 2

LD H,(HL) 7 2 66 1

LD H,(IX+o) 19 5 DD 66 oo 3

LD H,(IY+o) 19 5 FD 66 oo 3

LD H,n 7 2 26 nn 2

LD H,r 4 1 60+r 1

LD HL,(nn) 16 5 2A nn nn 5

LD HL,nn 10 3 21 nn nn 3

LD I,A 9 2 ED 47 2

LD IX,(nn) 20 6 DD 2A nn nn 4

LD IX,nn 14 4 DD 21 nn nn 4

LD IXh,n 11 3 DD 26 nn 2

LD IXh,p 8 2 DD 60+p 2

LD IXl,n 11 3 DD 2E nn 2

LD IXl,p 8 2 DD 68+p 2

LD IY,(nn) 20 6 FD 2A nn nn 4

LD IY,nn 14 4 FD 21 nn nn 4

LD IYh,n 11 3 FD 26 nn 2

LD IYh,q 8 2 FD 60+q 2

LD IYl,n 11 3 FD 2E nn 2

LD IYl,q 8 2 FD 68+q 2

LD L,(HL) 7 2 6E 1

LD L,(IX+o) 19 5 DD 6E oo 3

LD L,(IY+o) 19 5 FD 6E oo 3

LD L,n 7 2 2E nn 2

LD L,r 4 1 68+r 1

LD R,A 9 2 ED 4F 2

LD SP,(nn) 20 6 ED 7B nn nn 4

LD SP,HL 6 1 F9 1

LD SP,IX 10 2 DD F9 2

LD SP,IY 10 2 FD F9 2

LD SP,nn 10 3 31 nn nn 3

LDD 16 4 ED A8 2

LDDR 21/16 4 ED B8 2

LDI 16 4 ED A0 2

LDIR 21/16 4 ED B0 2

NEG 8 2 ED 44 2

NOP 4 1 00 1

OR (HL) 7 2 B6 1

OR (IX+o) 19 5 DD B6 oo 3

OR (IY+o) 19 5 FD B6 oo 3

OR n 7 2 F6 nn 2

OR r 4 1 B0+r 1

OR IXp 8 2 DD B0+p 2

OR IYq 8 2 FD B0+q 2

OTDR 21/16 4/3 ED BB 2

OTIR 21/16 4/3 ED B3 2

OUT (C),A 12 3 ED 79 2

OUT (C),B 12 3 ED 41 2

OUT (C),C 12 3 ED 49 2

OUT (C),D 12 3 ED 51 2

OUT (C),E 12 3 ED 59 2

OUT (C),H 12 3 ED 61 2

OUT (C),L 12 3 ED 69 2

OUT (n),A 11 3 D3 nn 2

OUTD 16 4 ED AB 2

OUTI 16 4 ED A3 2

POP AF 10 3 F1 1

POP BC 10 3 C1 1

POP DE 10 3 D1 1

POP HL 10 3 E1 1

POP IX 14 4 DD E1 2

POP IY 14 4 FD E1 2

PUSH AF 11 4 F5 1

PUSH BC 11 4 C5 1

PUSH DE 11 4 D5 1

PUSH HL 11 4 E5 1

PUSH IX 15 5 DD E5 2

PUSH IY 15 5 FD E5 2

RES b,(HL) 15 5 CB 86+8*b 2

RES b,(IX+o) 23 7 DD CB oo 86+8*b 4

RES b,(IY+o) 23 7 FD CB oo 86+8*b 4

RES b,r 8 2 CB 80+8*b+r 2

RET 10 3 C9 1

RET C 11/5 3/1 D8 1

RET M 11/5 3/1 F8 1

RET NC 11/5 3/1 D0 1

RET NZ 11/5 3/1 C0 1

RET P 11/5 3/1 F0 1

RET PE 11/5 3/1 E8 1

RET PO 11/5 3/1 E0 1

RET Z 11/5 3/1 C8 1

RETI 14 5 ED 4D 2

RETN 14 5 ED 45 2

RL (HL) 15 5 CB 16 2

RL (IX+o) 23 7 DD CB oo 16 4

RL (IY+o) 23 7 FD CB oo 16 4

RL r 8 2 CB 10+r 2

RLA 4 1 17 1

RLC (HL) 15 5 CB 06 2

RLC (IX+o) 23 7 DD CB oo 06 4

RLC (IY+o) 23 7 FD CB oo 06 4

RLC r 8 2 CB 00+r 2

RLCA 4 1 07 1

RLD 18 5 ED 6F 2

RR (HL) 15 5 CB 1E 2

RR (IX+o) 23 7 DD CB oo 1E 4

RR (IY+o) 23 7 FD CB oo 1E 4

RR r 8 2 CB 18+r 2

RRA 4 1 1F 1

RRC (HL) 15 5 CB 0E 2

RRC (IX+o) 23 7 DD CB oo 0E 4

RRC (IY+o) 23 7 FD CB oo 0E 4

RRC r 8 2 CB 08+r 2

RRCA 4 1 0F 1

RRD 18 5 ED 67 2

RST 0 11 4 C7 1

RST 8H 11 4 CF 1

RST 10H 11 4 D7 1

RST 18H 11 4 DF 1

RST 20H 11 4 E7 1

RST 28H 11 4 EF 1

RST 30H 11 4 F7 1

RST 38H 11 4 FF 1

SBC A,(HL) 7 2 9E 1

SBC A,(IX+o) 19 5 DD 9E oo 3

SBC A,(IY+o) 19 5 FD 9E oo 3

SBC A,n 7 2 DE nn 2

SBC A,r 4 1 98+r 1

SBC A,IXp 8 2 DD 98+p 2

SBC A,IYq 8 2 FD 98+q 2

SBC HL,BC 15 2 ED 42 2

SBC HL,DE 15 2 ED 52 2

SBC HL,HL 15 2 ED 62 2

SBC HL,SP 15 2 ED 72 2

SCF 4 1 37 1

SET b,(HL) 15 5 CB C6+8*b 2

SET b,(IX+o) 23 7 DD CB oo C6+8*b 4

SET b,(IY+o) 23 7 FD CB oo C6+8*b 4

SET b,r 8 2 CB C0+8*b+r 2

SLA (HL) 15 5 CB 26 2

SLA (IX+o) 23 7 DD CB oo 26 4

SLA (IY+o) 23 7 FD CB oo 26 4

SLA r 8 2 CB 20+r 2

SRA (HL) 15 5 CB 2E 2

SRA (IX+o) 23 7 DD CB oo 2E 4

SRA (IY+o) 23 7 FD CB oo 2E 4

SRA r 8 2 CB 28+r 2

SRL (HL) 15 5 CB 3E 2

SRL (IX+o) 23 7 DD CB oo 3E 4

SRL (IY+o) 23 7 FD CB oo 3E 4

SRL r 8 2 CB 38+r 2

SUB (HL) 7 2 96 1

SUB (IX+o) 19 5 DD 96 oo 3

SUB (IY+o) 19 5 FD 96 oo 3

SUB n 7 2 D6 nn 2

SUB r 4 1 90+r 1

SUB IXp 8 2 DD 90+p 2

SUB IYq 8 2 FD 90+q 2

XOR (HL) 7 2 AE 1

XOR (IX+o) 19 5 DD AE oo 3

XOR (IY+o) 19 5 FD AE oo 3

XOR n 7 2 EE nn 2

XOR r 4 1 A8+r 1

XOR IXp 8 2 DD A8+p 2

XOR IYq 8 2 FD A8+q 2

Abkürzungen:

b 3-bit value

n 8-bit value

nn 16-bit value

o 8-bit offset (2-complement)

r Register. Das kann sein: A, B, C, D, E, H, L

oder (HL). Der Wert wird zum letzten Byte

des Opcodes addiert.

Register Wert

A 7

B 0

C 1

D 2

E 3

H 4

L 5

(HL) 6

p, Ixp bezeichnet den High- oder Low-Anteil

des IX-Registers: IXh or IXl. Der

Wert wird zum letzten Byte des

Opcodes addiert.

Register Wert

A 7

B 0

C 1

D 2

E 3

IXh 4

IXl 5

q, Iyq bezeichnet den High- oder Low-Anteil

des IY-Registers: IYh or IYl. Der

Wert wird zum letzten Byte des

Opcodes addiert.

Register Wert

A 7

B 0

C 1

D 2

E 3

IYh 4

IYl 5

Hex-Table: ASCII-Table

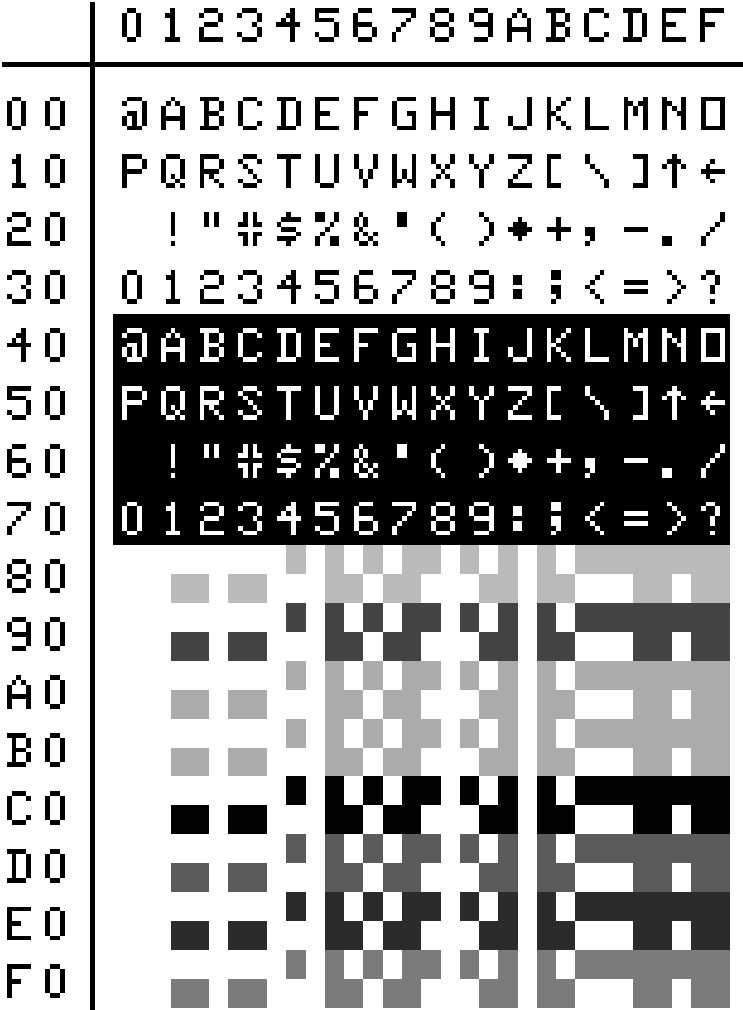
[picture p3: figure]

Speicherbelegung:

0000-1FFF ROM 0 8K (VZ-200)
2000-3FFF ROM 1 8K (VZ-200)
4000-5FFF DOS ROM 8K
6000-67FF RESERVED FOR ROM CARTRIDGES (2K)
6800-6FFF MEMORY MAPPED I/O 2K; KEYBOARD, CASSETTE I/O, SPEAKER, VDP CONTROOL
7000-77FF VIDEO RAM 2K
7800-8FFF INTERNAL USER RAM 6K (RESERVED RAM VZ-200)
9000-CFFF 16K EXPANSION (VZ-200)
7AE9 31465 START OF USER MEMORY
9000 36864 TOP OF MEMORY VZ-200 (6K)
B800 45184 TOP OF MEMORY VZ-300 (16K)
D000 53348 TOP OF MEMORY VZ-200 (6K + 16K EXPANSION)
F800 63488 TOP OF MEMORY VZ-300 (16K + 16k EXPANSION)
FFFF 65535 THE VERY TOP

Systemvariablen:

30790 STORES FOREGROUND COLOUR;

0,16,32,48,64,80,96,112

-colours green to orange
30845-7 INTERRUPT EXIT
30862-3 USR POINTER
30864 RND NUMBER SEED
30873 LAST KEY PRESSED
30880-1 BASIC STACK ADDRESS/LOWER BOUNDARY OF

STRING SPACE
30882-3 CURRENT BASIC LINE NUMBER/ADDRESS OF

LINE WITH ERROR
30884-5 START OF PROGRAM
30886 TAB CURSOR POSITION
30890-3 RANDOM NUMBER SEED
30897-8 TOP OF MEMORY POINTER
30969-70 END OF PROGRAM/START SIMPLE VARIABLES TABLE
30973-4 START OF FREE MEMORY
31003 TRACE FLAG 1=on 0=off

OUTPUT LATCH:

any address 6800-68FF / 26624-28671

hex dez bit

20 32 5 Speaker B

10 16 4 VDC Background Color

08 8 3 VDC Display Mode

04 4 2 Cassette Out (MSB)

02 2 1 Cassette Out (LSB)

01 1 0 Speaker A

VZ200-Remake github.com/cwahlmann/vz200-remake Seite 3 von 4

VZ200-Remake github.com/cwahlmann/vz200-remake Seite 4 von 4

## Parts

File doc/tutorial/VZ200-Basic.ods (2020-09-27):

REM <kommentar> | ein Kommentar | REM *** START ***
PRINT [<var1>;<...>;<varN>] | Ausgabe mit Zeilenumbruch | PRINT "HALLO";$N
PRINT <...>; | Ausgabe ohne Zeilenumbruch | PRINT "SAG MAL WAS";
PRINT @<n>,<...> | setzt den Cursor an die angegebenen Position, n=x+32*y | PRINT @128,"ZEILE 5"
PRINT TAB(<n>);<...> | setzt den Cursor weiter zu angegebenen Position innerhalb der Doppelzeile | PRINT TAB(3);“3“;TAB(20);“20“
PRINT USING <format>; <var1>,<…>,<varN> | Formatierte Ausgabe | PRINT USING "##.## / ##.##"; 1.23, 0.75
INPUT <var1>[,<...>,<varN>] | Eingabe von einer oder mehrerer Werte | INPUT A$, X, Y
NEW | Programmspeicher löschen | NEW
RUN [<n>] | Programm (ab Zeile n) starten | RUN 30
[LET] <var>=<wert> | Wert einer Variablen zuweisen | LET X=7 I%=-9 B$="PETER"
LIST [[n]-[m]] | Programm (Zeilen m bis n> auflisten | LIST -100
GOTO <n> | zu Zeile n springen | GOTO 20100
STOP | das Programm unterbrechen | STOP
CONT | das Programm fortführen | CONT
END | das Programm beenden (kein CONT mehr möglich) | END
CLEAR [<n>] | dem Programm n Bytes Speicher reservieren (Default: 50 bytes) | CLEAR 5000
ABS(<n>) | liefert den positiven Wert einer Zahl | X = ABS(-12.33):REM 12.33
SGN(<n>) | liefert das Vorzeichen einer Zahl (-1, 0 oder 1) | X = SGN(-12.33):REM -1
SQR(<n>) | liefert die Wurzel einer Zahl | E = SQR(25):REM 5
LOG(<n>) | liefert den natürlichen Logarithmus einer Zahl | L = LOG(4.44):REM 1.49065
EXP(<n>) | liefert den Wert e^n | E = EXP(1):REM 2.71828
INT(<n>) | liefert den ganzahligen Anteil einer Zahl | I = INT(1.9334):REM 1
RND(<n>) | liefert eine Zufallszahl zwischen 1 und n, oder eine rationale Zahl zwischen 0 und 1 für n=0 | IF RND(2)=1 THEN PRINT "TOP" ELSE PRINT "FLOPP"
SIN(<n>) | liefert den Sinuswert einer Zahl | W=30:Y = SIN(W/180*3.1415):REM .499987
COS(<n>) | liefert den Cosinuswert einer Zahl | X = COS(W/180*3.1415):REM .866033
TAN(<n>) | liefert den Tangenswert einer Zahl | T = TAN(W/180*3.1415):REM .57733
ATN(<n>) | liefert den Arcus-Tangenswert einer Zahl | W = ATN(X/Y)/3.1415*180:REM 30
LEN(<string>) | liefert die Länge eines Strings | PRINT LEN("HALLO")
STR$(<n>) | wandelt eine Zahl in einen String um | PRINT STR$(1277):REM "1277"
VAL(<string>) | wandelt einen String in eine Zahl um | PRINT VAL("1277"):REM 1277
LEFT$(<string>, <n>) | liefert die ersten n Zeichen eines Strings | L$ = LEFT$("NINA",2): REM NI
RIGHT$(<string>, <n>) | liefert die n letzten Zeichen eines Strings | R$ = RIGHT$("NINA",2):REM NA
MID$(<string>, <m>, <n>) | liefert n Zeichen ab Position m eines Strings | M$ = MID$("NINA",2,2):REM IN
ASC(<string>) | liefert den Ascii-Wert des ersten Zeichens eines Strings | PRINT ASC("A"):REM 65
CHR$(<n>) | wandelt einen Ascii-Wert in einen String um | PRINT CHR$(65):REM A
INKEY$ | liest ein Zeichen von der Tastatur, ohne zu warten | 10 IF INKEY$="" THEN 10
IF <bedingung> THEN <befehl-true> [ELSE <befehl-false>] | Bedingte Ausführung, je nach Ergebnis der Bedingung | IF A>=2 THEN PRINT "MEHRERE ERBSEN" ELSE PRINT "EINE ERBSE" IF X=0 THEN PRINT "NULL"
= < > <= >= <> | Vergleichsoperatoren
<bool> AND|OR|NOT <bool> | logische Und/Oder/Nicht-Verknüpfung | 20 IF A=2 AND B=3 THEN 40
<n> AND|OR|NOT <m> | bitweise Und/Oder/Nicht-Verknüpfung | E = 3 OR 6:REM 7
FOR <var>=<n> TO <m> [STEP <s>] | Zählt var von n bis m (mit Schrittweite s) | FOR I=10 TO 1 STEP -1:PRINT I:NEXT
NEXT [<var>] | springe zum nächsten Schleifendurchlauf (der Indexvariable var) | NEXT I
GOSUB <n> | Aufruf des Unterprogramms ab Zeile n | GOSUB 12345
RETURN | Unterprogramm beenden | RETURN
DIM <var>(<m>[,<n>[,<o>]]) | Arrayvariablen deklarieren (1, 2 oder 3-dimensional) | DIM R$(2,5)
DATA <n1>[,<n2>,<...>] | Daten bereitstellen | DATA 1,2,"PILLE",3,4,"PALLE"
READ <var1>[,<var2>,<...>] | Daten in Variablen einlesen | READ A,B,M$
RESTORE | Beim Lesen von Daten wieder von vorne beginnen | RESTORE
PEEK(<adresse>) | liefert Wert einer Speicherstelle | B = PEEK(28672)
POKE <adresse>,<wert> | schreibt einen Wert in den Speicher | POKE 28672,1:REM EIN "A" LINKS OBEN AM SCREEN
CLOAD ["<filename>") | lädt ein Programm von Cassette | CLOAD "SUPERSPIEL"
CRUN ["<filename>") | führt ein Programm von Cassette aus | CRUN "MEGASPOILER"
CSAVE ["<filename>") | Schreibt ein Programm auf Cassette | CSAVE "MEINS"
VERIFY ["<filename>") | Vergleicht auf Cassette gespeichertes Programm mit dem aktuellen Programm im Speicher | VERIFY "MEINS"
PRINT# "<filename>", <wert1> [,<wert2><...>] | Schreibt Werte auf Cassette | PRINT# "DATEN",1,2,"PILLE"
INPUT# "<filename>", <var1> [,<var2><...>] | liest Werte von Cassette | INPUT# "DATEN",A,B,M$
MODE(<n>) | setzt den Grafikmodus (0 = Text, 1 = Hires) | MODE(1)
SET(<x>,<y>) | setzt einen Grafikpunkt | SET(10,10)
RESET(<x>,<y>) | löscht einen Grafikpunkt | RESET(9,10)
POINT(<x>,<y>) | liefert die Farbe eines Grafikpunkts | 60 IF POINT(9,10)=0 THEN 100
COLOR [<vordergrund>][,<palette>] | Setzt Vordergrundfarbe und / oder die Hintergrundfarbe | COLOR 4: REM VORDERGRUND BLAU COLOR ,0: REM HINTERGRUND GRÜN COLOR 1,1: REM GELB / CYAN
SOUND <note>,<länge> | Spielt einen Ton ab note: 0 = Pause; 1 = A2; 31 = D#5 länge: 1-4 = n/8; 5= ¾; 7 = 1 ½; 6-9 = 1-3 | SOUND 13,7:SOUND 0,4:SOUND 15,7
INP(<n>) | liest einen Wert von Port n | B=INP(123)
OUT <n>,<wert> | schreibt einen Wert in Port n | OUT 123,4
USR(<n>) | Ruft eine benutzerdefinierte Maschinenroutine auf. Startadresse: 788e (30862) Wert n:7921 (31009) | POKE 30862,LO:REM LOWBYTE DES PRG POKE 30863,HI:REM HIGHBYTE DES PRG E=USR(1234)
LLIST, LPRINT | wie LIST und PRINT, aber auf Druckerport | LLIST LPRINT "HALLO DRUCKER"
COPY | macht einen Screenshot auf dem Druckerport | COPY
Variablennamen | [A-Z]([A-Z0-9])?(%|$)? | A1$="MOIN": XY=9.333
String | eine Zeichenkette | S$="GUTEN TAG"
Float | eine Fließkommezahl zwischen -1.701411E+/-38 und -1.701411E+/-38 | PI=3.1415927:m=1E9
Integer | eine Ganzzahl zwischen -32768 und 32767 | Z9%=16384
Textmodus | 32x16 Zeichen, 8 Farben, 2 Hintergrundfarben | grün, gelb, blau, rot, weiss, türkis, magenta, orange / grün, orange
Grafikmodus | 128x64 Pixel, 4 Farben, 2 Paletten | grün, gelb, blau, rot / weiss, türkis, magenta, orange

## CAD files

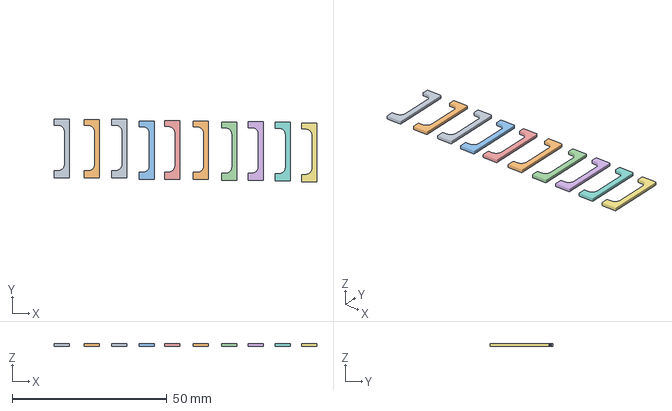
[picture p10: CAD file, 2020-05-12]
3d-model/drucke/Cura/CE3_VZ200_Resetschalter-Klemme_x10.3mf
84.9 x 20.2 x 1.00 mm

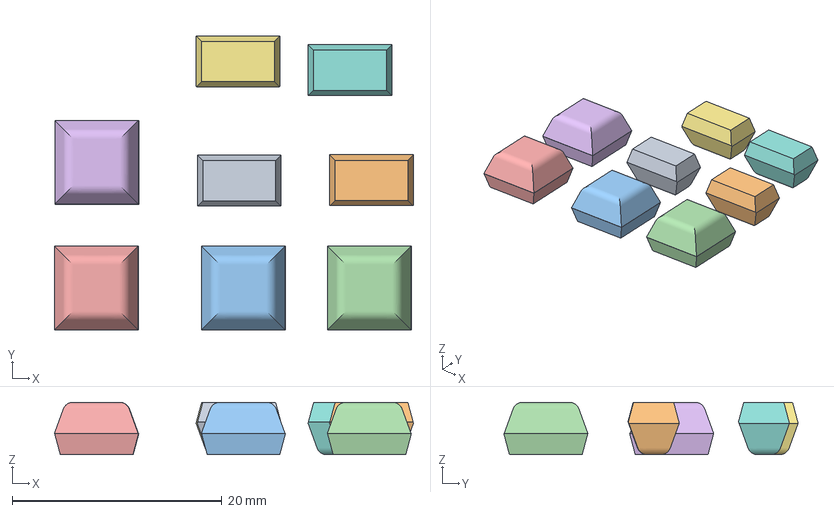
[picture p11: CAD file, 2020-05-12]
3d-model/drucke/gcode/CE3_Monitor-Füße-x2_TPU.3mf
34.2 x 28.0 x 5.00 mm

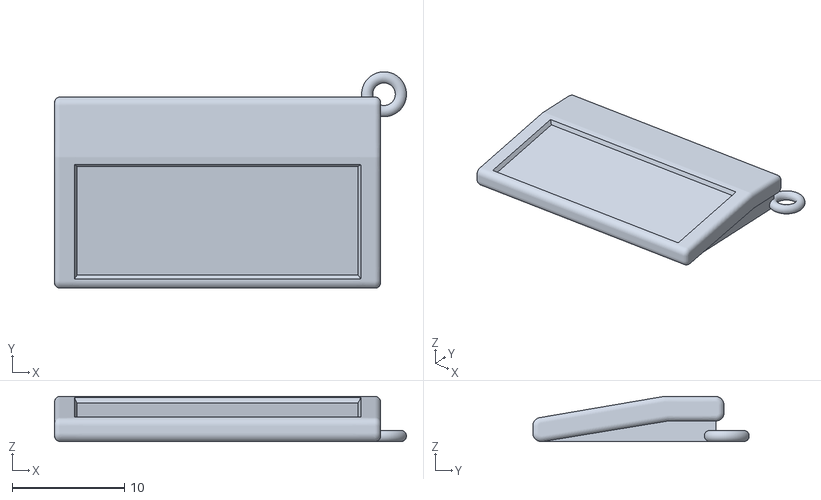
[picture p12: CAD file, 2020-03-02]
3d-model/drucke/stl/VZ200 10% Anhänger.stl
31.3 x 19.2 x 4.02

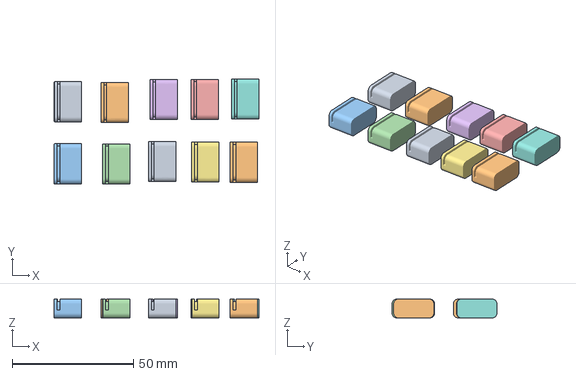
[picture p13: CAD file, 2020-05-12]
3d-model/drucke/Cura/CE3_VZ200_Resetschalter70%_x10.3mf
84.7 x 43.4 x 7.84 mm

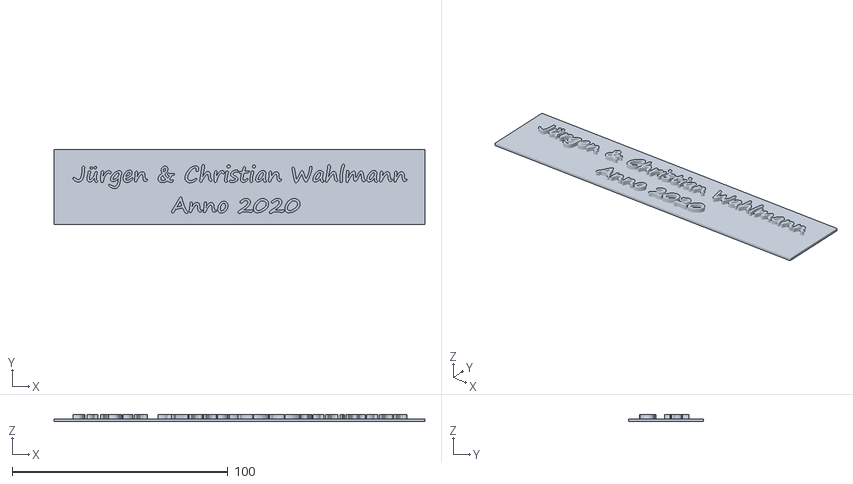
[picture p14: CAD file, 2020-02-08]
3d-model/drucke/stl/Signatur v2.stl
172.0 x 35.0 x 3.20

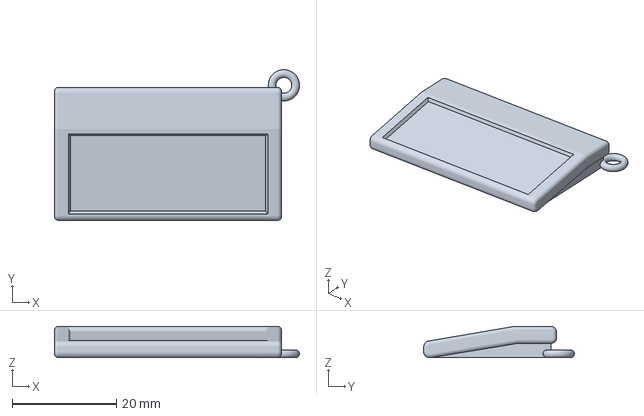
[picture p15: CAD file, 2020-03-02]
3d-model/drucke/Cura/CE3_VZ200 15% Anhanger.3mf
46.9 x 28.9 x 6.02 mm

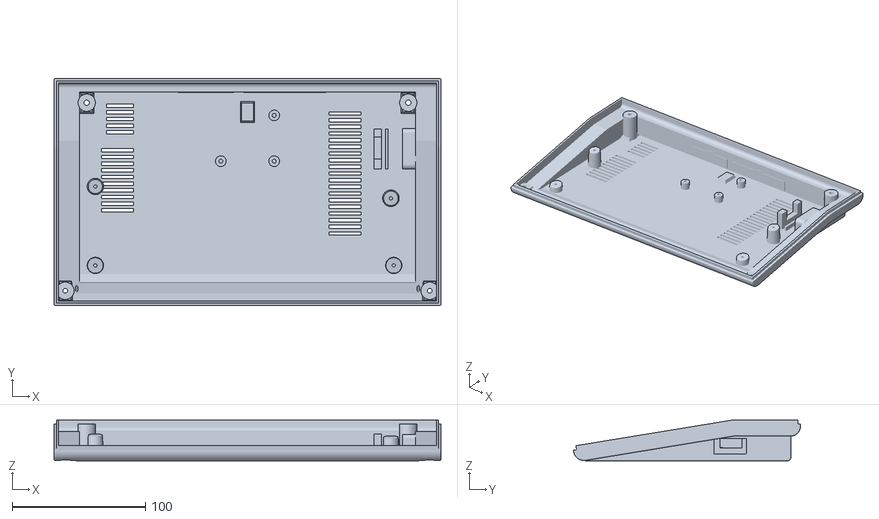
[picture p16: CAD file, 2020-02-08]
3d-model/drucke/stl/VZ200_Gehäuse unten_signatur_100%.stl
290.2 x 170.1 x 30.5

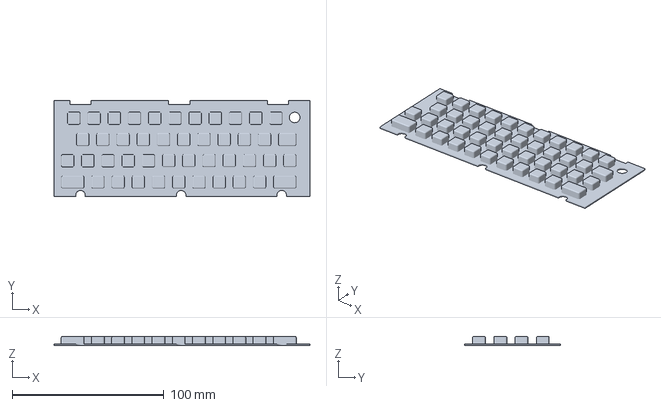
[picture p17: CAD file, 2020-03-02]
3d-model/drucke/Cura/CE3_VZ200_Tastatur Tasten_5.5_70%.3mf
168.5 x 63.0 x 5.95 mm

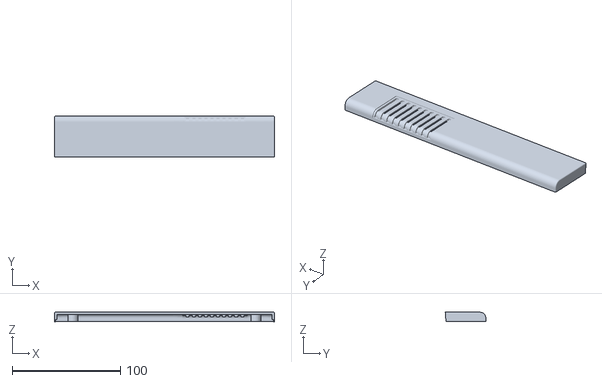
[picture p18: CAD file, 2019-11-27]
3d-model/drucke/stl/VZ200_Gehäuse oben hinten_70%.stl
203.0 x 37.4 x 8.81

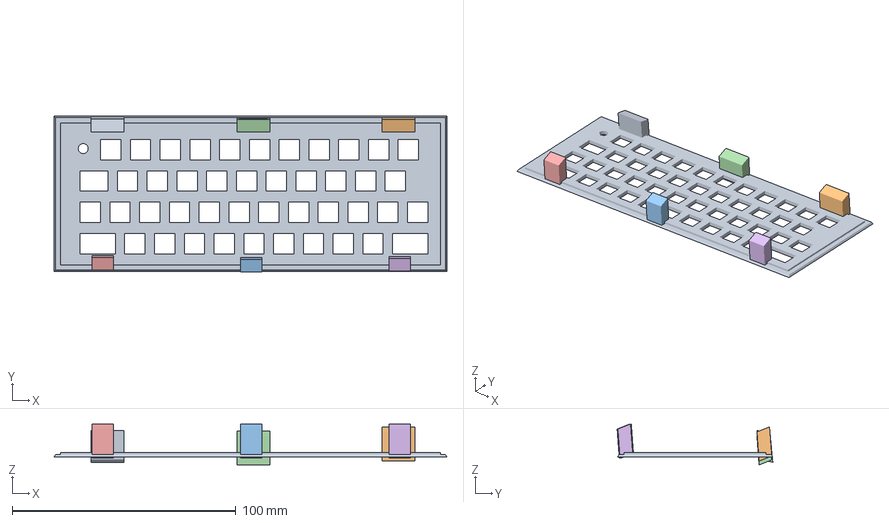
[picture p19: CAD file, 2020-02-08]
3d-model/drucke/Cura/CE3_Tastaturschablone70Prozent.3mf
175.7 x 69.6 x 18.3 mm

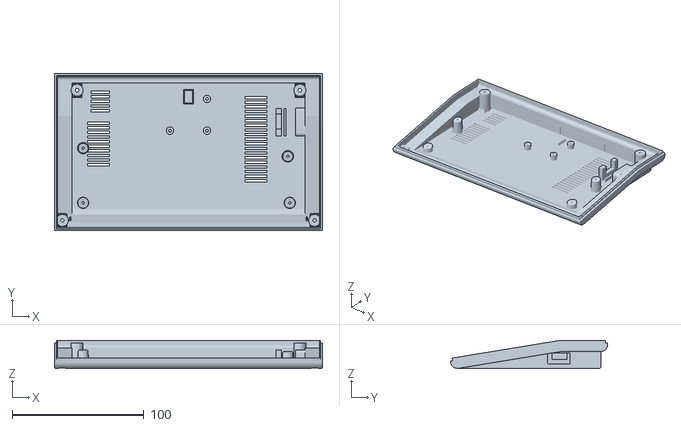
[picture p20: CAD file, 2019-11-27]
3d-model/drucke/stl/VZ200_Gehäuse unten_70%.stl
203.1 x 119.0 x 21.3

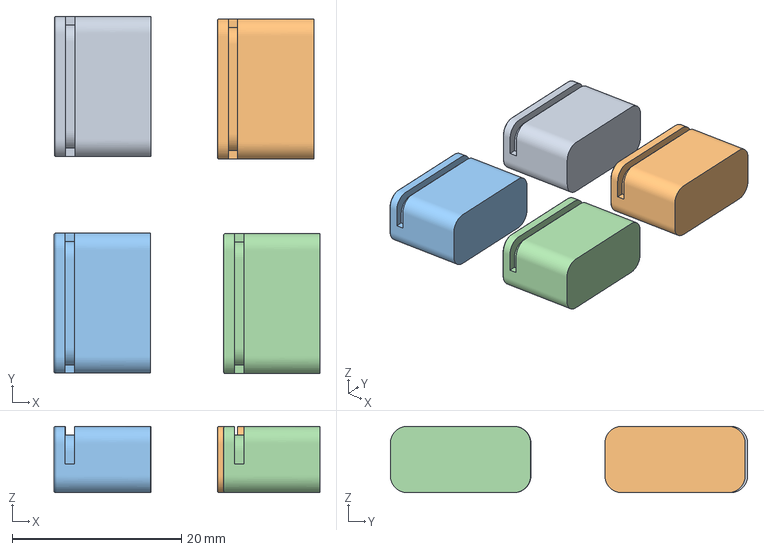
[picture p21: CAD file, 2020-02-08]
3d-model/drucke/Cura/CE3_VZ200_Resetschalter70%_x4.3mf
31.5 x 42.3 x 7.84 mm

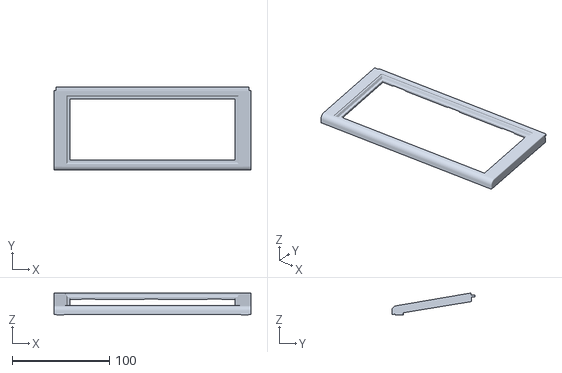
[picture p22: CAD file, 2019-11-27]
3d-model/drucke/stl/VZ200_Gehäuse oben vorn_70%.stl
203.0 x 85.9 x 22.7

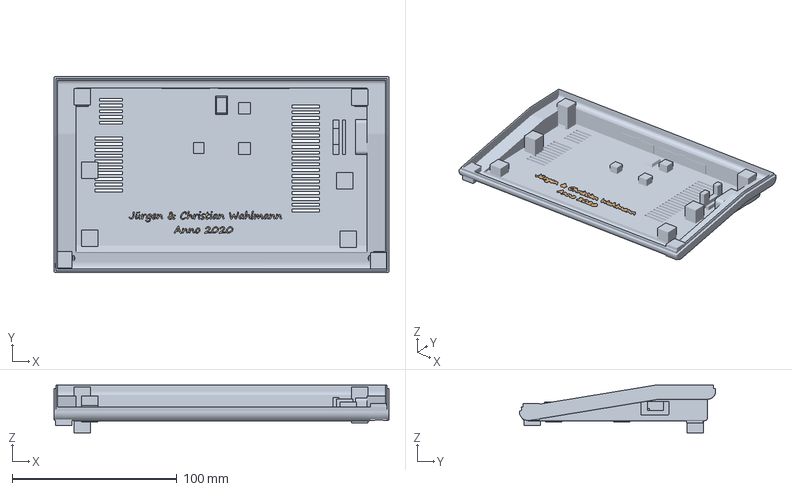
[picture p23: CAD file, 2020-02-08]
3d-model/drucke/Cura/CE3_VZ200_Gehause unten_signatur_70%.3mf
203.1 x 119.1 x 29.1 mm

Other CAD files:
3d-model/drucke/stl/VZ200_Gehäuse unten_rechteSeite_test_70%.stl
3d-model/drucke/Cura/CE3_VZ200_Gehause oben_vorn_70Prozent.3mf
3d-model/drucke/stl/VZ200_Tastatur Rahmen_70%.stl
3d-model/drucke/Cura/CE3_VZ200_Gehause oben_hinten_70Prozent.3mf
3d-model/Monitor_5-Zoll.f3d
3d-model/drucke/Cura/CE3_Applikationen-vorne.3mf
3d-model/drucke/Cura/CE3_Fuß.3mf
3d-model/drucke/Cura/CE3_Lautsprecher-Halterung.3mf
3d-model/drucke/Cura/CE3_Monitor-Fuß-vorne.3mf
3d-model/drucke/Cura/CE3_Monitor-Gehause-hinten.3mf
3d-model/drucke/Cura/CE3_Monitor-Gehause-vorn.3mf
3d-model/drucke/Cura/CE3_Monitor_VorderseiteMitFüßen_PLA_White.3mf
3d-model/drucke/Cura/CE3_VZ200-Schild.3mf
3d-model/drucke/Cura/CE3_VZ200_Gehause unten_70%.3mf
3d-model/drucke/Cura/CE3_VZ200_Leisten unten 70%.3mf
3d-model/drucke/Cura/CE3_VZ200_Resetschalter-Klemme70%.3mf
3d-model/drucke/Cura/CE3_VZ200_Resetschalter70%.3mf
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

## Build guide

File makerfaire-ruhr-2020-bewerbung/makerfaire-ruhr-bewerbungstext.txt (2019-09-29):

Wie heißt euer Stand?
---------------------

VZ200-Remake

Beschreibt euren Stand in einem Wort oder Satz. (max. 300)
-----------------------------------------------------

Mit einem funktionstüchtigen Nachbau des "VZ200 Color Computer" von 1983 lassen wir die Welt der 8-Bit Computer wieder auferstehen.

(129 Zeichen)

Beschreibt euer Projekt (max. 800)
-----------------------------

Vom Platinendesign über 3D-Druck bis hin zum fertigen Rechner in schnuckeligen 70%: hier kannst du den kompletten
(Neu-)Entstehungsprozess des Computers miterleben, auf dem wir unsere ersten Gehversuche in der Welt der IT gemacht haben.

Während der ganzen Messe schrauben und löten wir Modelle zusammen. Ihr könnt uns dabei über die Schulter schauen,
und auch gerne selbst Hand anlegen. Was wir gemeinsam produziert haben, werden wir im Laufe der Messe verlosen.

Ob Space-Invader oder Hallo Welt - fertige Modelle des "VZ200 Color Computer" stehen zum Ausprobieren bereit.

Zu diesen Zeiten steigen wir tiefer in einzelne Themen ein:

11:00h - 3D-Design und -Druck
14:00h - Platinenlayout mit KiCad
16:00h - Basic- und Assembler-Programmierung

cwahlmann.github.io/vz200-remake

(791 Zeichen)

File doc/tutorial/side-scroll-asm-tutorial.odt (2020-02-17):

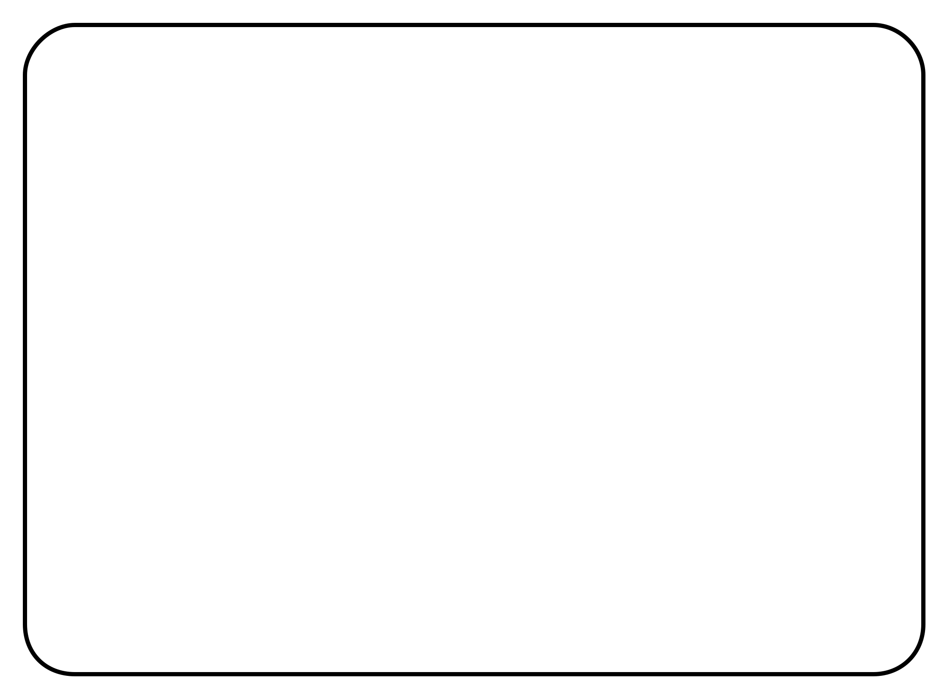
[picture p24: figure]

ASSEMBLERPROGRAMM SIDE-SCROLL.ASM:

.org 0x7200 // Programm in Grafikspeicher laden

.run 0x7200 // und dort auch starten

.def screen: 0x7000 // Bildschirmspeicheradresse

LD HL, screen: // HL = Bildschirm Startadresse

LD DE, screen: // DE = Bildschirm Startadresse + 1

INC DE

LD BC, 0x01ff // BC = Zähler

loop: // Schleife 1

LD A, (DE) // Zeichen aus DE laden

LD (HL), A // und nach HL schreiben

INC HL // Adresspointer erhöhen

INC DE

DEC BC // Zähler - 1

LD A, B // Zähler = 0 ?

OR C

JR NZ, loop: // nein, weiter

LD HL, screen: // HL = Bildschirm Startadresse

LD DE, 0x0020 // DE = Zeilenlänge

ADD HL, DE // HL + Zeilenlänge - 1 = Ende der 1. Zeile

DEC HL

LD B, 0x10 // B = Zähler für 16 Zeilen

LD A, 0x20 // A = Leerzeichen

loop2: // Schleife

LD (HL), A // Leerzeichen schreiben

ADD HL, DE // nächste Zeile

DEC B // Zähler - 1

JR NZ, loop2: // weiter, solange Zähler != 0

RET // Ende

KODIERUNG IN Z80-MASCHINENODE:

HEX | DEZIMAL | ASSEMBLER |

21 00 70 | 33, 0, 112 | LD HL,0x7000 | HL = Bildschirm

| | | Startadresse

11 00 70 | 17, 0, 112 | LD DE,0x7000 | DE = Bildschirm

| | | Startadresse + 1

13 | 19 | INC DE |

01 ff 01 | 1, 255, 1 | LD BC,0x01FF | BC = Zähler

1a | 26 | LD A,(DE) | Schleife 1; Zeichen aus

| | | DE laden

77 | 119 | LD (HL),A | und nach HL schreiben

23 | 35 | INC HL | Adresspointer erhöhen

13 | 19 | INC DE |

0b | 11 | DEC BC | Zähler - 1

78 | 120 | LD A,B | Zähler = 0 ?

b1 | 177 | OR C |

20 f7 | 32, 247 | JR NZ, -9 | nein, weiter

21 00 70 | 33, 0, 112 | LD HL,0x7000 | HL = Bildschirm

| | | Startadresse

11 20 00 | 17, 32, 00 | LD DE,0x0020 | DE = Zeilenlänge

19 | 25 | ADD HL,DE | HL + Zeilenlänge - 1 =

| | | Ende der 1. Zeile

2b | 43 | DEC HL |

06 10 | 6, 16 | LD B,0x10 | B = Zähler für 16 Zeilen

3e 20 | 62, 32 | LD A, 0x20 | A = Leerzeichen

77 | 119 | LD (HL), A | Schleife 2; Leerzeichen

| | | schreiben

19 | 25 | ADD HL,DE | nächste Zeile

05 | 5 | DEC B | Zähler - 1

20 fb | 32, 251 | JR NZ, -4 | weiter, solange Zähler!=0

c9 | 201 | RET | Ende

BASIC-PROGRAMM:

10 REM *** SCROLL-LEFT-DEMO ***

20 CLS:COLOR,0

30 PRINT"***** SIDE SCROLLING DEMO *****"

40 PRINT@160," <W> UP"

50 PRINT" <S> DOWN"

50 PRINT" <X> EXIT"

40 PRINT@320," !! TRY TO AVOID STARS !! "

60 PRINT@480," LOADING ASSEMBLER ...";

80 GOSUB 900:SOUND 0,5

90 CLS:COLOR,1:P=165:Q=165

100 REM *** GAME LOOP ***

110 PRINT@Q," ";

120 X=USR(X)

125 IF PEEK(28672+P+3)<>32 THEN PRINT@P-2,"%=#$!#";:GOTO140

130 PRINT@P,">=-";

140 POKE 28672+31+32*(RND(16)-1), 42

150 Q=P

170 B$=INKEY$

180 IF P>=32 AND B$="W" THEN P=P-32

190 IF P<480 AND B$="S" THEN P=P+32

200 IF B$<>"X" THEN 100

210 CLS:COLOR,0

220 END

900 REM *** ASM-PROGRAMM-INSTALLIEREN ***

910 A = 28672 + 512

920 A1 = INT(A / 256): A0 = A - 256 * A1

930 POKE 30862, A0:POKE 30863, A1

940 READ B:REM *** BYTE-LESEN

950 IF B > 255 THEN RETURN:REM *** FERTIG?

960 POKE A, B:REM *** BYTE-SCHREIBEN

970 A=A+1

980 GOTO 940

1000 DATA 33, 0, 112, 17, 0, 112, 19, 1

1010 DATA 255, 1, 26, 119, 35, 19, 11, 120

1020 DATA 177, 32, 247, 33, 0, 112, 17, 32

1030 DATA 00, 25, 43, 6, 16, 62, 32, 119

1040 DATA 25, 5, 32, 251, 201

1020 DATA 999

READY

RUN

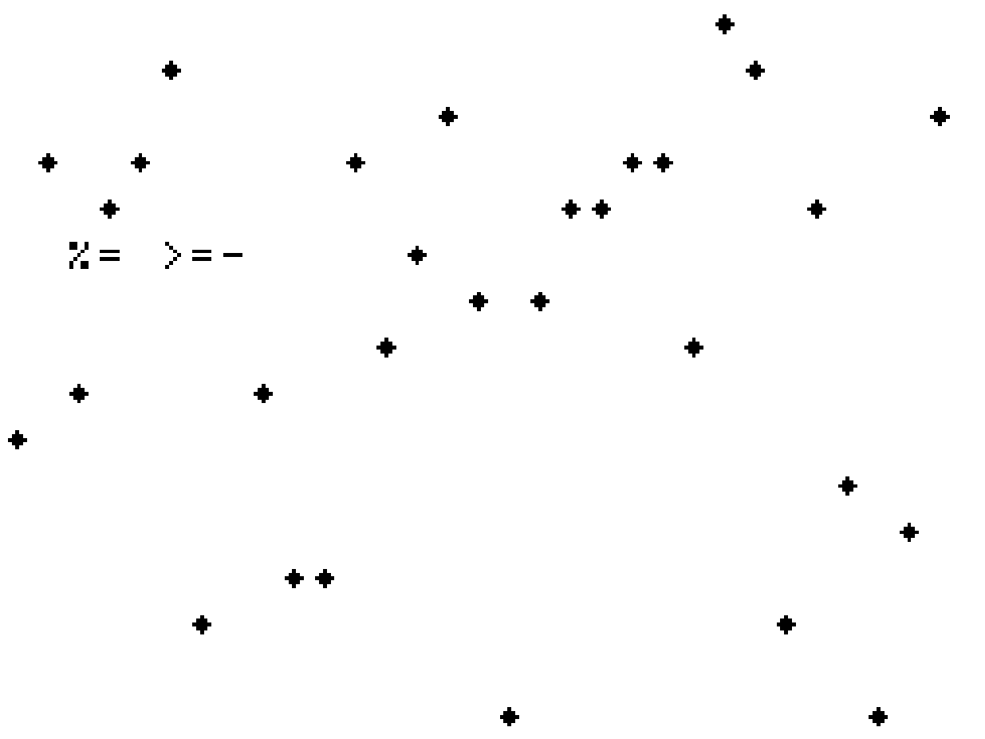
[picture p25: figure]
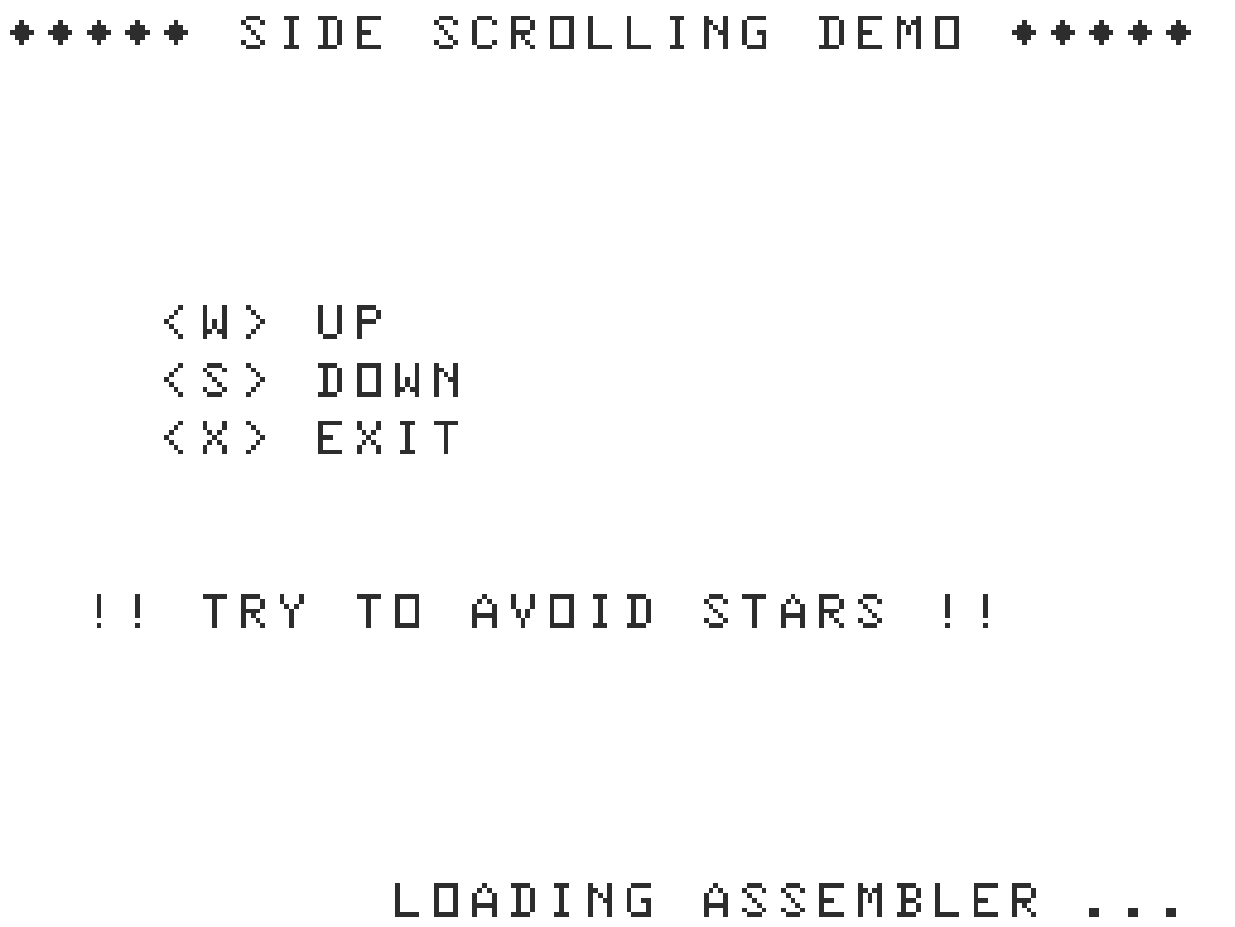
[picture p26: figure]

VZ200-Remake github.com/cwahlmann/vz200-remake Seite 4 von 4

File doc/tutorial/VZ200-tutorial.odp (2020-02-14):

## VZ200 Basic Tutorial „hello-world“

BASICPROGRAMM HELLO-WORLD.BAS:

10 CLS

20 FOR I=0 TO 511

30 POKE 28672+I, I AND 255

40 NEXT

50 GOTO 50

RUN

## VZ200 Basic Tutorial „hello-world“

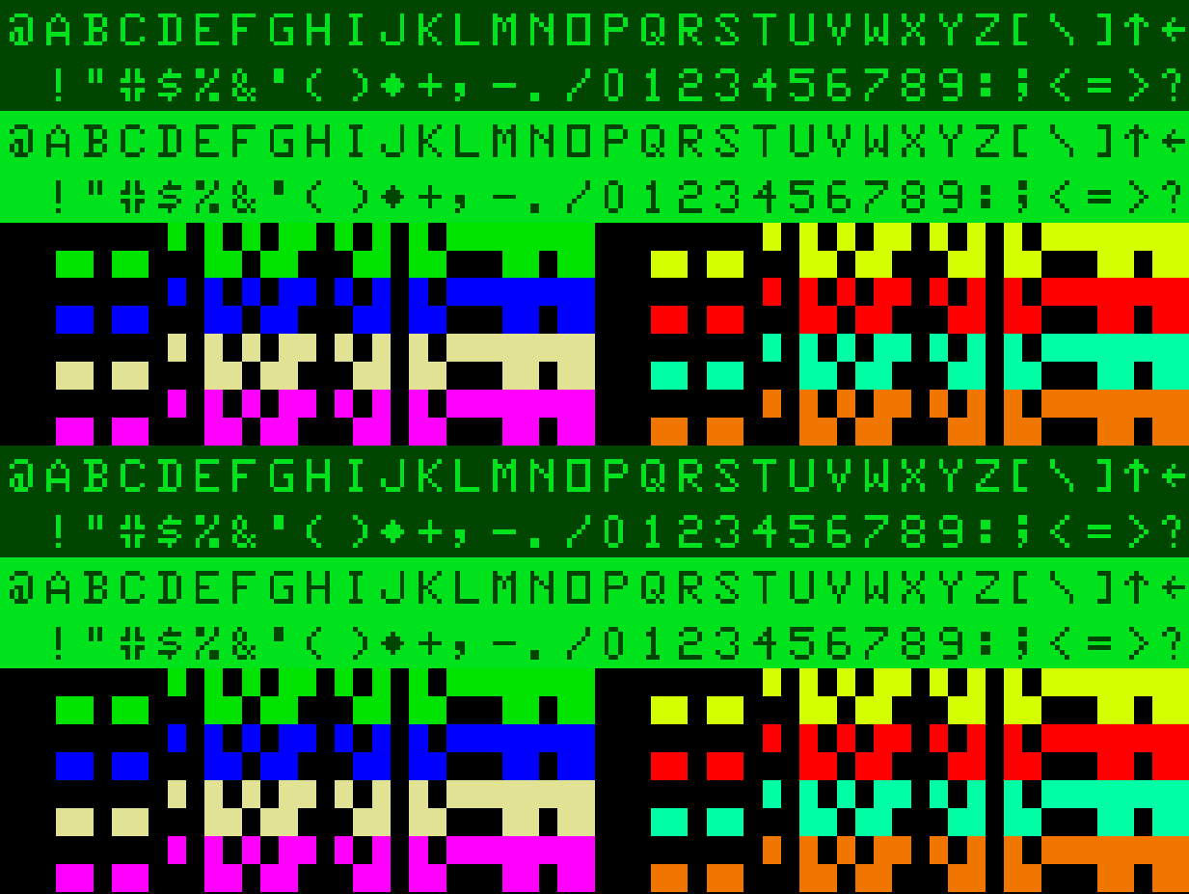
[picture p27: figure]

## VZ200 Basic & Assembler Tutorial „hello-world“

ASSEMBLERPROGRAMM HELLO-WORLD.ASM:

.org 0x7200 // Programm in Grafikspeicher laden

.run 0x7200 // und dort auch starten

.def screen: 0x7000 // Bildschirmspeicheradresse

LD HL, screen: // Bildschirmspeicheradresse in HL

LD BC, 0x0200 // Zähler = Länge des Bildschirmspeichers

// im Textmodus

LD D, 0x00 // aktuelles Zeichen beginnend mit @

loop: // Schleife

LD (HL), D // Zeichen in Bildschirmspeicher laden

INC HL // nächste Adresse

INC D // nächstes Zeichen

DEC BC // Zähler runterzählen

LD A, B // Test, ob Zähler = 0

OR C

JR NZ, loop: // Nein? weiter in der

RET // Programm beenden

## VZ200 Basic & Assembler Tutorial „hello-world“

KODIERUNG IN Z80-MASCHINENCODE:

ASM | HEX | DEZIMAL |

LD HL,0x7000 | 21 00 70 | 33, 0, 112 | Bildschirmspeicheradresse
| | | in HL

LD BC,0x0200 | 01 00 02 | 1, 0, 2 | Zähler = Länge des
| | | Bildschirmspeichers im

| | | Textmodus

LD D,0x00 | 16 00 | 22, 0 | aktuelles Zeichen

| | | (beginnend mit @)

LD (HL),D | 72 | 114 | Schleife; Zeichen in Bild-

| | | schirmspeicher laden

INC HL | 23 | 35 | nächste Adresse

INC D | 14 | 20 | nächstes Zeichen

DEC BC | 0b | 11 | Zähler runterzählen

LD A,B | 78 | 120 | Test, ob Zähler = 0

OR C | b1 | 177 |

JR NZ, -8 | 20 f8 | 32 248 | Schleife

RET | c9 | 201 | Programm beenden

## VZ200 Basic & Assembler Tutorial „hello-world“

BASIC-PROGRAMM:

10 REM --- HALLO-WELT-ASSEMBLER ---
20 A = 28672 + 512: REM *** HIRES-SCREEN-MEM
30 READ B:REM *** BYTE-LESEN
40 IF B > 255 THEN 80:REM *** FERTIG?
50 POKE A, B:REM *** BYTE-SCHREIBEN
60 A=A+1
70 GOTO 30
80 REM *** USR-POINTER-SCHREIBEN
90 POKE 30862, 0
100 POKE 30863, 114: REM 72
120 X=USR(X):REM *** MASCHINEN-PROGRAMN-STARTEN
130 GOTO 130
1000 DATA 33, 0, 112, 1, 0, 2, 22, 0,
1010 DATA 114, 35, 20, 11, 120, 177, 32, 248, 201
1020 DATA 999

RUN

## VZ200 Basic & Assembler Tutorial „hello-world“

## VZ200 Basic & Assembler Tutorial „side-scrolling“

| | | | | | | | | | | | | | | | | | | | | | | | | | | | | | | X
| | | | | | | | | | | | | | | | | | | | | | | | | | | | | | | X
| | | | | | | | | | | | | | | | | | | | | | | | | | | | | | | X
| | | | | | | | | | | | | | | | | | | | | | | | | | | | | | | X
| | | | | | | | | | | | | | | | | | | | | | | | | | | | | | | X
| | | | | | | | | | | | | | | | | | | | | | | | | | | | | | | X
| | | | | | | | | | | | | | | | | | | | | | | | | | | | | | | X
| | | | | | | | | | | | | | | | | | | | | | | | | | | | | | | X
| | | | | | | | | | | | | | | | | | | | | | | | | | | | | | | X
| | | | | | | | | | | | | | | | | | | | | | | | | | | | | | | X
| | | | | | | | | | | | | | | | | | | | | | | | | | | | | | | X
| | | | | | | | | | | | | | | | | | | | | | | | | | | | | | | X
| | | | | | | | | | | | | | | | | | | | | | | | | | | | | | | X
| | | | | | | | | | | | | | | | | | | | | | | | | | | | | | | X
| | | | | | | | | | | | | | | | | | | | | | | | | | | | | | | X
| | | | | | | | | | | | | | | | | | | | | | | | | | | | | | | X

## VZ200 Basic & Assembler Tutorial „side-scrolling“

ASSEMBLERPROGRAMM SIDE-SCROLL.ASM:

.org 0x7200

.run 0x7200

.def screen: 0x7000

LD HL, screen: // HL = Bildschirm

// Startadresse

LD DE, screen: // DE = Bildschirm // Startadresse+1

INC DE

LD BC, 0x01ff // BC = Zähler

loop: // Schleife 1

LD A, (DE) // Zeichen aus DE
// laden

LD (HL), A // und nach HL
// schreiben

INC HL // Adresspointer

// erhöhen

INC DE

DEC BC // Zähler - 1

LD A, B // Zähler = 0 ?

OR C

JR NZ, loop: // nein, weiter

LD HL, screen: // HL = Bildschirm

// Startadresse

LD DE, 0x0020 // DE = Zeilenlänge

ADD HL, DE // HL+Zeilenlänge

// -1 = Ende der

// 1. Zeile

DEC HL

LD B, 0x10 // B = Zähler für

// 16 Zeilen

LD A, 0x20 // A = Leerzeichen

loop2: // Schleife

LD (HL), A // Leerzeichen

// schreiben

ADD HL, DE // nächste Zeile

DEC B // Zähler - 1

JR NZ, loop2: // weiter, solange
// Zähler != 0

RET // Ende

## VZ200 Basic & Assembler Tutorial „side-scrolling“

KODIERUNG IN Z80-MASCHINENCODE:

HEX | DEZIMAL | ASSEMBLER |

21 00 70 | 33, 0, 112 | LD HL,0x7000 | HL = Bildschirm

| | | Startadresse

11 00 70 | 17, 0, 112 | LD DE,0x7000 | DE = Bildschirm

| | | Startadresse + 1

13 | 19 | INC DE |

01 ff 01 | 1, 255, 1 | LD BC,0x01FF | BC = Zähler

1a | 26 | LD A,(DE) | Schleife 1; Zeichen aus

| | | DE laden

77 | 119 | LD (HL),A | und nach HL schreiben

23 | 35 | INC HL | Adresspointer erhöhen

13 | 19 | INC DE |

0b | 11 | DEC BC | Zähler - 1

78 | 120 | LD A,B | Zähler = 0 ?

b1 | 177 | OR C |

20 f7 | 32, 247 | JR NZ, -9 | nein, weiter

21 00 70 | 33, 0, 112 | LD HL,0x7000 | HL = Bildschirm

| | | Startadresse

11 20 00 | 17, 32, 00 | LD DE,0x0020 | DE = Zeilenlänge

19 | 25 | ADD HL,DE | HL + Zeilenlänge - 1 =

| | | Ende der 1. Zeile

2b | 43 | DEC HL |

06 10 | 6, 16 | LD B,0x10 | B = Zähler für 16 Zeilen

3e 20 | 62, 32 | LD A, 0x20 | A = Leerzeichen

77 | 119 | LD (HL), A | Schleife 2; Leerzeichen

| | | schreiben

19 | 25 | ADD HL,DE | nächste Zeile

05 | 5 | DEC B | Zähler - 1

20 fb | 32, 251 | JR NZ, -4 | weiter, solange Zähler!=0

c9 | 201 | RET | Ende

## VZ200 Basic & Assembler Tutorial „side-scrolling“

BASIC-PROGRAMM:

10 REM *** SCROLL-LEFT-DEMO ***

20 CLS:COLOR,0

30 PRINT"***** SIDE SCROLLING DEMO *****"

40 PRINT@160," <W> UP"

50 PRINT" <S> DOWN"

50 PRINT" <X> EXIT"

40 PRINT@320," !! TRY TO AVOID STARS !! "

60 PRINT@480," LOADING ASSEMBLER ...";

80 GOSUB 900:SOUND 0,5

90 CLS:COLOR,1:P=165:Q=165

100 REM *** GAME LOOP ***

110 PRINT@Q," ";

120 X=USR(X)

125 IF PEEK(28672+P+3)<>32 THEN PRINT@P-2,"%=#$!#";:GOTO140

130 PRINT@P,">=-";

140 POKE 28672+31+32*(RND(16)-1), 42

150 Q=P

170 B$=INKEY$

180 IF P>=32 AND B$="W" THEN P=P-32

190 IF P<480 AND B$="S" THEN P=P+32

200 IF B$<>"X" THEN 100

210 CLS:COLOR,0

220 END

900 REM *** ASM-PROGRAMM-INSTALLIEREN ***

910 A = 28672 + 512

920 A1 = INT(A / 256): A0 = A - 256 * A1

930 POKE 30862, A0:POKE 30863, A1

940 READ B:REM *** BYTE-LESEN

950 IF B > 255 THEN RETURN:REM *** FERTIG?

960 POKE A, B:REM *** BYTE-SCHREIBEN

970 A=A+1

980 GOTO 940

1000 DATA 33, 0, 112, 17, 0, 112, 19, 1

1010 DATA 255, 1, 26, 119, 35, 19, 11, 120

1020 DATA 177, 32, 247, 33, 0, 112, 17, 32

1030 DATA 00, 25, 43, 6, 16, 62, 32, 119

1040 DATA 25, 5, 32, 251, 201

1020 DATA 999

READY

RUN

## VZ200 Basic & Assembler Tutorial „side-scrolling“

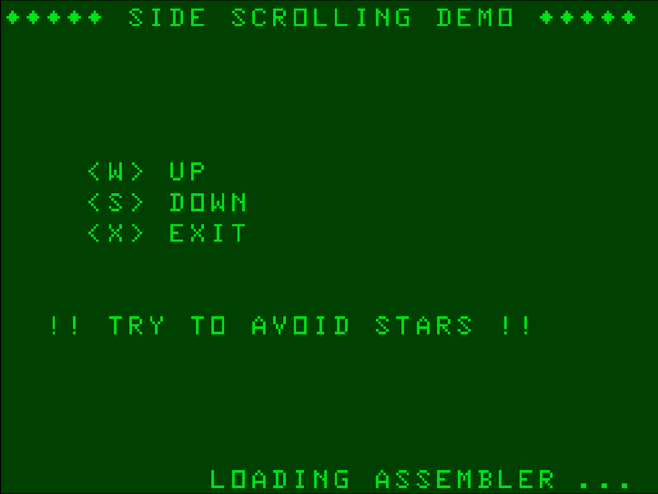
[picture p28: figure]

## VZ200 Basic & Assembler Tutorial „side-scrolling“

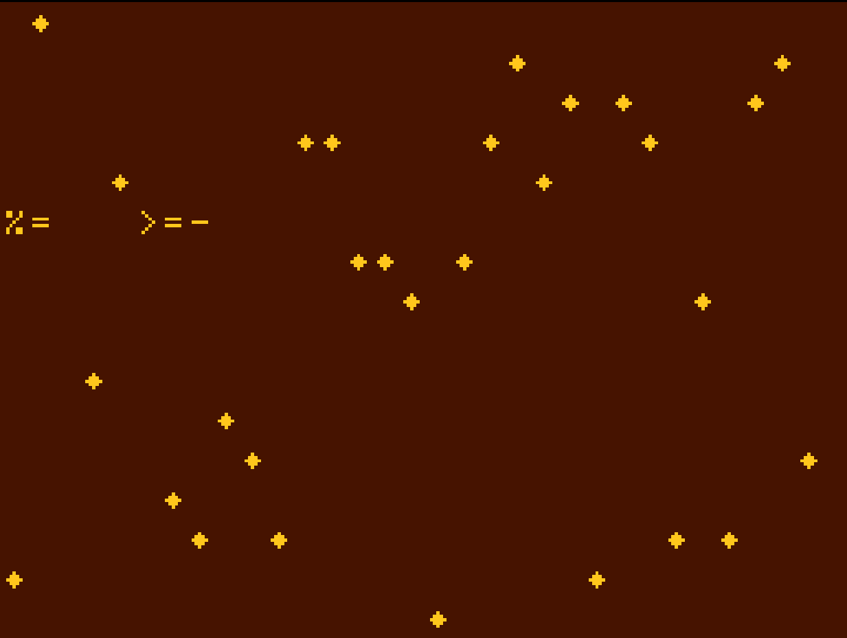
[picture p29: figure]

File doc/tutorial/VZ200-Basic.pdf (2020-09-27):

VZ200 Basic Cheat Sheet

VZ200-Remake | github.com/cwahlmann/vz200-remake | Seite 1 von 2
REM <kommentar> | ein Kommentar | REM *** START ***
PRINT [<var1>;<...>;<varN>] | Ausgabe mit Zeilenumbruch | PRINT "HALLO";$N
PRINT <...>; | Ausgabe ohne Zeilenumbruch | PRINT "SAG MAL WAS";
PRINT @<n>,<...> | | PRINT @128,"ZEILE 5"
PRINT TAB(<n>);<...> | | PRINT TAB(3);“3“;TAB(20);“20“
| Formatierte Ausgabe
INPUT <var1>[,<...>,<varN>] | Eingabe von einer oder mehrerer Werte | INPUT A$, X, Y
NEW | Programmspeicher löschen | NEW
RUN [<n>] | Programm (ab Zeile n) starten | RUN 30
[LET] <var>=<wert> | Wert einer Variablen zuweisen
LIST [[n]-[m]] | Programm (Zeilen m bis n> auflisten | LIST -100
GOTO <n> | zu Zeile n springen | GOTO 20100
STOP | das Programm unterbrechen | STOP
CONT | das Programm fortführen | CONT
END | | END
CLEAR [<n>] | | CLEAR 5000
ABS(<n>) | liefert den positiven Wert einer Zahl | X = ABS(-12.33):REM 12.33
SGN(<n>) | | X = SGN(-12.33):REM -1
SQR(<n>) | liefert die Wurzel einer Zahl | E = SQR(25):REM 5
LOG(<n>) | | L = LOG(4.44):REM 1.49065
EXP(<n>) | liefert den Wert e^n | E = EXP(1):REM 2.71828
INT(<n>) | liefert den ganzahligen Anteil einer Zahl | I = INT(1.9334):REM 1

RND(<n>)

SIN(<n>) | liefert den Sinuswert einer Zahl
COS(<n>) | liefert den Cosinuswert einer Zahl | X = COS(W/180*3.1415):REM .866033
TAN(<n>) | liefert den Tangenswert einer Zahl | T = TAN(W/180*3.1415):REM .57733
ATN(<n>) | liefert den Arcus-Tangenswert einer Zahl | W = ATN(X/Y)/3.1415*180:REM 30
LEN(<string>) | liefert die Länge eines Strings | PRINT LEN("HALLO")
STR$(<n>) | wandelt eine Zahl in einen String um | PRINT STR$(1277):REM "1277"
VAL(<string>) | wandelt einen String in eine Zahl um | PRINT VAL("1277"):REM 1277
LEFT$(<string>, <n>) | liefert die ersten n Zeichen eines Strings | L$ = LEFT$("NINA",2): REM NI
RIGHT$(<string>, <n>) | liefert die n letzten Zeichen eines Strings | R$ = RIGHT$("NINA",2):REM NA
MID$(<string>, <m>, <n>) | liefert n Zeichen ab Position m eines Strings M$ = MID$("NINA",2,2):REM IN
ASC(<string>) | | PRINT ASC("A"):REM 65
CHR$(<n>) | wandelt einen Ascii-Wert in einen String um | PRINT CHR$(65):REM A
INKEY$ | | 10 IF INKEY$="" THEN 10
= < > <= >= <> | Vergleichsoperatoren
<bool> AND|OR|NOT <bool> | logische Und/Oder/Nicht-Verknüpfung | 20 IF A=2 AND B=3 THEN 40

setzt den Cursor an die angegebenen Position, n=x+32*y
setzt den Cursor weiter zu angegebenen Position innerhalb der Doppelzeile PRINT USING <format>;
<var1>,<…>,<varN>

PRINT USING "##.## / ##.##"; 1.23, 0.75

LET X=7
I%=-9
B$="PETER"

das Programm beenden (kein CONT mehr möglich)
dem Programm n Bytes Speicher reservieren (Default: 50 bytes)

liefert das Vorzeichen einer Zahl (-1, 0 oder 1)

liefert den natürlichen Logarithmus einer Zahl

liefert eine Zufallszahl zwischen 1 und n, oder eine rationale Zahl zwischen 0 und 1 für n=0

IF RND(2)=1 THEN PRINT "TOP" ELSE PRINT "FLOPP"

W=30:Y = SIN(W/180*3.1415):REM .499987

liefert den Ascii-Wert des ersten Zeichens eines Strings

liest ein Zeichen von der Tastatur, ohne zu warten
IF <bedingung>
THEN <befehl-true>
[ELSE <befehl-false>]

Bedingte Ausführung, je nach Ergebnis der Bedingung

IF A>=2 THEN PRINT "MEHRERE ERBSEN" ELSE PRINT "EINE ERBSE" IF X=0 THEN PRINT "NULL"

VZ200 Basic Cheat Sheet

VZ200-Remake | github.com/cwahlmann/vz200-remake | Seite 2 von 2
<n> AND|OR|NOT <m> | bitweise Und/Oder/Nicht-Verknüpfung | E = 3 OR 6:REM 7
| Zählt var von n bis m (mit Schrittweite s) | FOR I=10 TO 1 STEP -1:PRINT I:NEXT
NEXT [<var>] | | NEXT I
GOSUB <n> | Aufruf des Unterprogramms ab Zeile n | GOSUB 12345
RETURN | Unterprogramm beenden | RETURN
DIM <var>(<m>[,<n>[,<o>]]) | | DIM R$(2,5)
DATA <n1>[,<n2>,<...>] | Daten bereitstellen | DATA 1,2,"PILLE",3,4,"PALLE"
READ <var1>[,<var2>,<...>] | Daten in Variablen einlesen | READ A,B,M$
RESTORE | | RESTORE
PEEK(<adresse>) | liefert Wert einer Speicherstelle | B = PEEK(28672)
POKE <adresse>,<wert> | schreibt einen Wert in den Speicher
CLOAD ["<filename>") | lädt ein Programm von Cassette | CLOAD "SUPERSPIEL"
CRUN ["<filename>") | führt ein Programm von Cassette aus | CRUN "MEGASPOILER"
CSAVE ["<filename>") | Schreibt ein Programm auf Cassette | CSAVE "MEINS"
VERIFY ["<filename>") | | VERIFY "MEINS"
| Schreibt Werte auf Cassette | PRINT# "DATEN",1,2,"PILLE"
| liest Werte von Cassette | INPUT# "DATEN",A,B,M$
MODE(<n>) | | MODE(1)
SET(<x>,<y>) | setzt einen Grafikpunkt | SET(10,10)
RESET(<x>,<y>) | löscht einen Grafikpunkt | RESET(9,10)
POINT(<x>,<y>) | liefert die Farbe eines Grafikpunkts | 60 IF POINT(9,10)=0 THEN 100
SOUND <note>,<länge> | | SOUND 13,7:SOUND 0,4:SOUND 15,7
INP(<n>) | liest einen Wert von Port n | B=INP(123)
OUT <n>,<wert> | schreibt einen Wert in Port n | OUT 123,4

USR(<n>)

LLIST, LPRINT | wie LIST und PRINT, aber auf Druckerport
COPY | | COPY
Variablennamen | [A-Z]([A-Z0-9])?(%|$)? | A1$="MOIN": XY=9.333
String | eine Zeichenkette | S$="GUTEN TAG"
Float | | PI=3.1415927:m=1E9
Integer | eine Ganzzahl zwischen -32768 und 32767 | Z9%=16384

Textmodus

Grafikmodus | 128x64 Pixel, 4 Farben, 2 Paletten

FOR <var>=<n> TO <m>
[STEP <s>]
springe zum nächsten Schleifendurchlauf (der Indexvariable var)

Arrayvariablen deklarieren (1, 2 oder 3-dimensional)

Beim Lesen von Daten wieder von vorne beginnen

POKE 28672,1:REM EIN "A" LINKS OBEN AM SCREEN

Vergleicht auf Cassette gespeichertes Programm mit dem aktuellen Programm im Speicher
PRINT# "<filename>",
<wert1> [,<wert2><...>]
INPUT# "<filename>",
<var1> [,<var2><...>]
setzt den Grafikmodus
(0 = Text, 1 = Hires)

COLOR [<vordergrund>]
[,<palette>]

Setzt Vordergrundfarbe und / oder die Hintergrundfarbe

COLOR 4: REM VORDERGRUND BLAU COLOR ,0: REM HINTERGRUND GRÜN COLOR 1,1: REM GELB / CYAN Spielt einen Ton ab
note: 0 = Pause; 1 = A2; 31 = D#5 länge: 1-4 = n/8; 5= ¾; 7 = 1 ½; 6-9 = 1-3

Ruft eine benutzerdefinierte Maschinenroutine auf.
Startadresse: 788e (30862) Wert n:7921 (31009)

POKE 30862,LO:REM LOWBYTE DES PRG POKE 30863,HI:REM HIGHBYTE DES PRG E=USR(1234)

LLIST
LPRINT "HALLO DRUCKER"
macht einen Screenshot auf dem Druckerport

eine Fließkommezahl zwischen -1.701411E+/-38 und -1.701411E+/-38

32x16 Zeichen,
8 Farben, 2 Hintergrundfarben

grün, gelb, blau, rot, weiss, türkis, magenta, orange / grün, orange grün, gelb, blau, rot / weiss, türkis, magenta, orange

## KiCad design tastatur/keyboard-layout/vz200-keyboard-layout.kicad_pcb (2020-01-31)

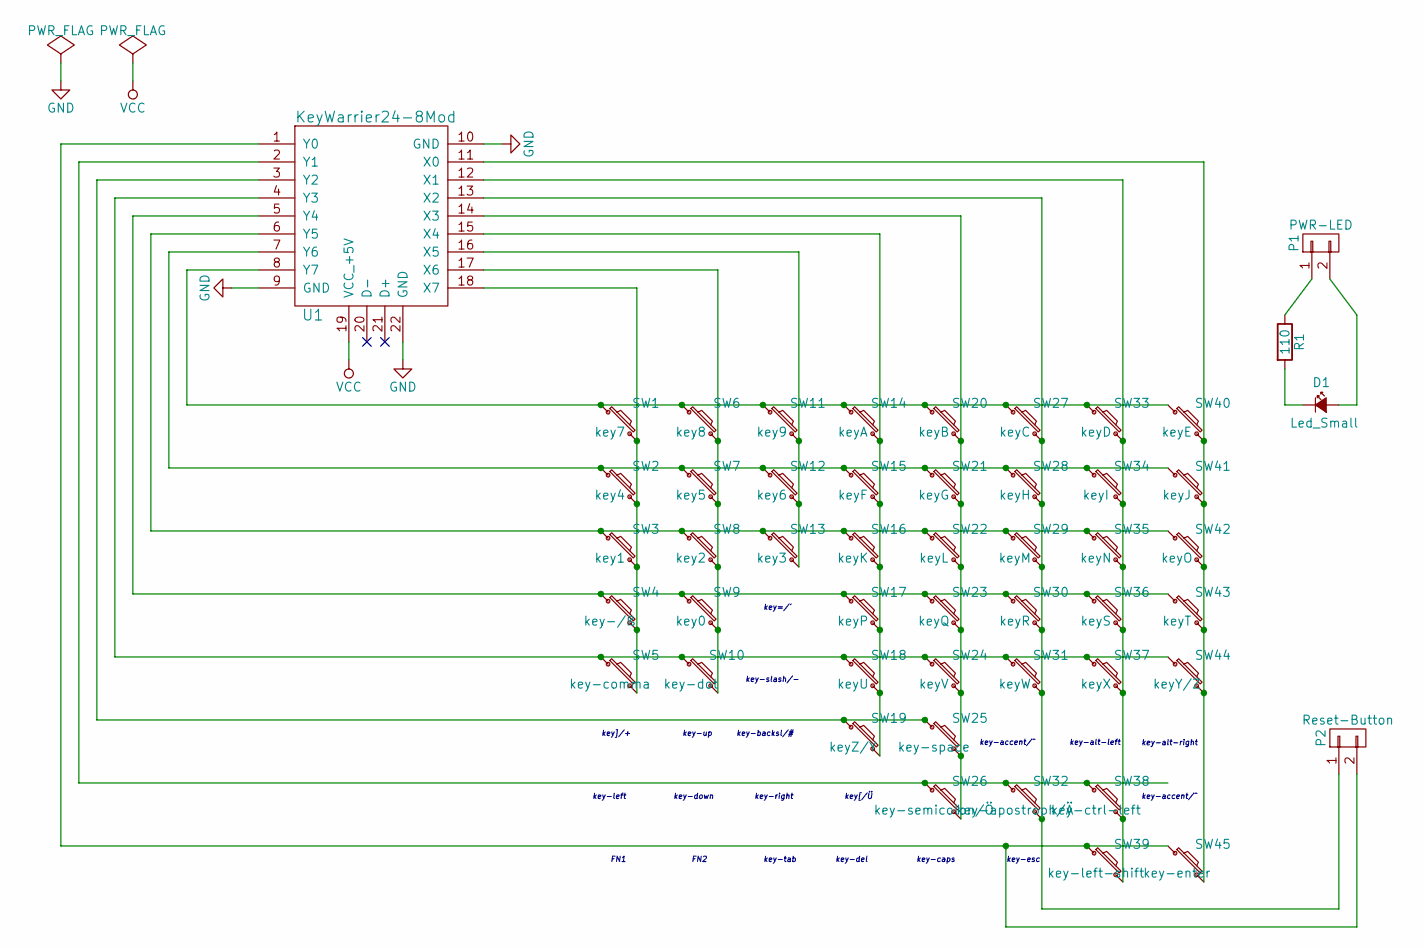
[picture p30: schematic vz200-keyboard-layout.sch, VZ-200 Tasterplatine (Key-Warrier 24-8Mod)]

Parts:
D1: Led_Small; LED_D1.8mm_W3.3mm_H2.4mm
P1: PWR-LED; Pin_Header_Straight_1x02_Pitch2.54mm
P2: Reset-Button; Pin_Header_Straight_1x02_Pitch2.54mm
R1: 110; R_Axial_DIN0204_L3.6mm_D1.6mm_P7.62mm_Horizontal
SW1: key7; SW_PUSH_6mm
SW2: key4; SW_PUSH_6mm
SW3: key1; SW_PUSH_6mm
SW4: key-/ß; SW_PUSH_6mm
SW5: key-comma; SW_PUSH_6mm
SW6: key8; SW_PUSH_6mm
SW7: key5; SW_PUSH_6mm
SW8: key2; SW_PUSH_6mm
SW9: key0; SW_PUSH_6mm
SW10: key-dot; SW_PUSH_6mm
SW11: key9; SW_PUSH_6mm
SW12: key6; SW_PUSH_6mm
SW13: key3; SW_PUSH_6mm
SW14: keyA; SW_PUSH_6mm
SW15: keyF; SW_PUSH_6mm
SW16: keyK; SW_PUSH_6mm
SW17: keyP; SW_PUSH_6mm
SW18: keyU; SW_PUSH_6mm
SW19: keyZ/Y; SW_PUSH_6mm
SW20: keyB; SW_PUSH_6mm
SW21: keyG; SW_PUSH_6mm
SW22: keyL; SW_PUSH_6mm
SW23: keyQ; SW_PUSH_6mm
SW24: keyV; SW_PUSH_6mm
SW25: key-space; SW_PUSH_6mm
SW26: key-semicolon/Ö; SW_PUSH_6mm
SW27: keyC; SW_PUSH_6mm
SW28: keyH; SW_PUSH_6mm
SW29: keyM; SW_PUSH_6mm
SW30: keyR; SW_PUSH_6mm
SW31: keyW; SW_PUSH_6mm
SW32: key-apostroph/Ä; SW_PUSH_6mm
SW33: keyD; SW_PUSH_6mm
SW34: keyI; SW_PUSH_6mm
SW35: keyN; SW_PUSH_6mm
SW36: keyS; SW_PUSH_6mm
SW37: keyX; SW_PUSH_6mm
SW38: key-ctrl-left; SW_PUSH_6mm
SW39: key-left-shift; SW_PUSH_6mm
SW40: keyE; SW_PUSH_6mm
SW41: keyJ; SW_PUSH_6mm
SW42: keyO; SW_PUSH_6mm
SW43: keyT; SW_PUSH_6mm
SW44: keyY/Z; SW_PUSH_6mm
SW45: key-enter; SW_PUSH_6mm
U1: KeyWarrier24-8Mod; Socket_Strip_Straight_1x22_Pitch2.54mm

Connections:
GND: U1.9 (GND), U1.10 (GND), U1.22 (GND)
unnamed: D1.1 (K), R1.2
unnamed: D1.2 (A), P1.2
unnamed: P1.1, R1.1
unnamed: P2.1, SW27.2, SW28.2, SW29.2, SW30.2, SW31.2, SW32.2, U1.13 (X2)
unnamed: P2.2, SW39.1, SW45.1, U1.1 (Y0)
unnamed: SW1.1, SW6.1, SW11.1, SW14.1, SW20.1, SW27.1, SW33.1, SW40.1, U1.8 (Y7)
unnamed: SW1.2, SW2.2, SW3.2, SW4.2, SW5.2, U1.18 (X7)
unnamed: SW5.1, SW10.1, SW18.1, SW24.1, SW31.1, SW37.1, SW44.1, U1.4 (Y3)
unnamed: SW6.2, SW7.2, SW8.2, SW9.2, SW10.2, U1.17 (X6)
unnamed: SW11.2, SW12.2, SW13.2, U1.16 (X5)
unnamed: SW2.1, SW7.1, SW12.1, SW15.1, SW21.1, SW28.1, SW34.1, SW41.1, U1.7 (Y6)
unnamed: SW3.1, SW8.1, SW13.1, SW16.1, SW22.1, SW29.1, SW35.1, SW42.1, U1.6 (Y5)
unnamed: SW14.2, SW15.2, SW16.2, SW17.2, SW18.2, SW19.2, U1.15 (X4)
unnamed: SW4.1, SW9.1, SW17.1, SW23.1, SW30.1, SW36.1, SW43.1, U1.5 (Y4)
unnamed: SW19.1, SW25.1, U1.3 (Y2)
unnamed: SW20.2, SW21.2, SW22.2, SW23.2, SW24.2, SW25.2, SW26.2, U1.14 (X3)
unnamed: SW26.1, SW32.1, SW38.1, U1.2 (Y1)
unnamed: SW33.2, SW34.2, SW35.2, SW36.2, SW37.2, SW38.2, SW39.2, U1.12 (X1)
unnamed: SW40.2, SW41.2, SW42.2, SW43.2, SW44.2, SW45.2, U1.11 (X0)
VCC: U1.19 (VCC_+5V)

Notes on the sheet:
key=/´
key-slash/-
key]/+
key-backsl/#
key-accent/^
key-alt-left
key-alt-right
key[/Ü
FN1
FN2
key-tab
key-del
key-caps
key-esc
key-left
key-up
key-down
key-right

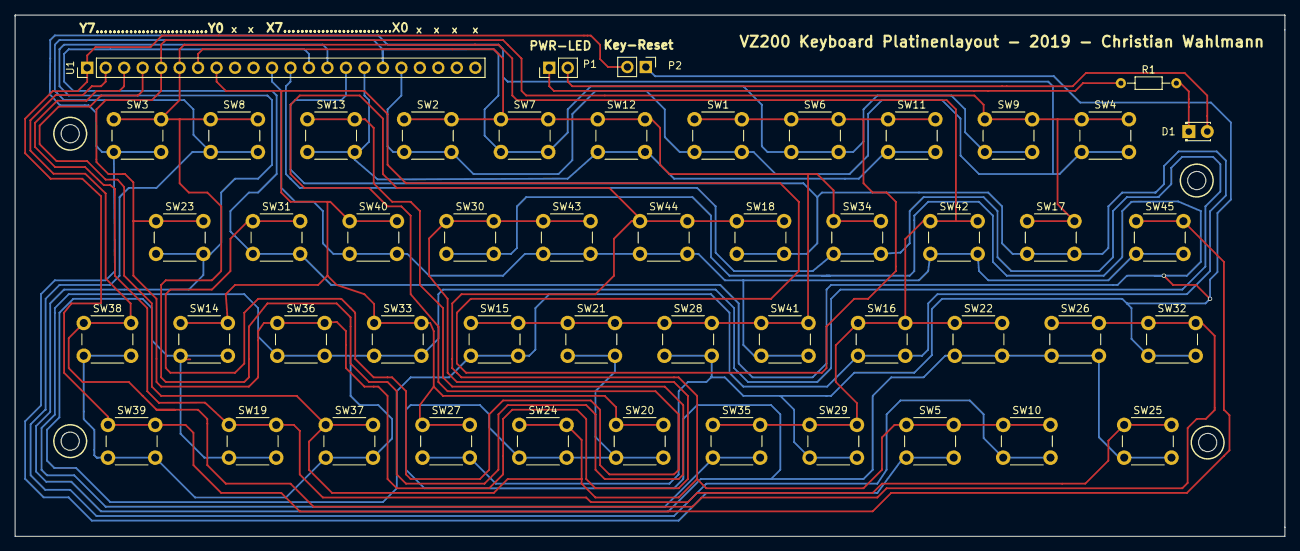
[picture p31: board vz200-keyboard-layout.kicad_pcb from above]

Board: 2 copper layers, 174.5 x 71.6 mm, 50 parts (0 on the bottom side), 20 nets.

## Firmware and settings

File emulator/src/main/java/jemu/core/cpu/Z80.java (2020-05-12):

package jemu.core.cpu;

import jemu.core.*;

/**
 * This file is part of JemuVz200, an enhanced VZ200 emulator,
 * based on the works of Richard Wilson (2002) - see http://jemu.winape.net
 * <p>
 * The software is open source by the conditions of the GNU General Public Licence 3.0. See the copy of the GPL 3.0
 * (gpl-3.0.txt) you received with this software.
 *
 * @author Christian Wahlmann
 */

public class Z80 extends Processor {

	// =============================================================
	// Timings for instructions. This is standard Z80 T-States.
	// =============================================================

	protected static final byte[] Z80_TIME_PRE = { 4, 10, 7, 6, 4, 4, 7, 4, 4, 11, 7, 6, 4, 4, 7, 4, // 00 .. 0F
			8, 10, 7, 6, 4, 4, 7, 4, 12, 11, 7, 6, 4, 4, 7, 4, // 10 .. 1F
			7, 10, 16, 6, 4, 4, 7, 4, 7, 11, 16, 6, 4, 4, 7, 4, // 20 .. 2F
			7, 10, 13, 6, 11, 11, 10, 4, 7, 11, 13, 6, 4, 4, 7, 4, // 30 .. 3F
			4, 4, 4, 4, 4, 4, 7, 4, 4, 4, 4, 4, 4, 4, 7, 4, // 40 .. 4F
			4, 4, 4, 4, 4, 4, 7, 4, 4, 4, 4, 4, 4, 4, 7, 4, // 50 .. 5F
			4, 4, 4, 4, 4, 4, 7, 4, 4, 4, 4, 4, 4, 4, 7, 4, // 60 .. 6F
			7, 7, 7, 7, 7, 7, 4, 7, 4, 4, 4, 4, 4, 4, 7, 4, // 70 .. 7F
			4, 4, 4, 4, 4, 4, 7, 4, 4, 4, 4, 4, 4, 4, 7, 4, // 80 .. 8F
			4, 4, 4, 4, 4, 4, 7, 4, 4, 4, 4, 4, 4, 4, 7, 4, // 90 .. 9F
			4, 4, 4, 4, 4, 4, 7, 4, 4, 4, 4, 4, 4, 4, 7, 4, // A0 .. AF
			4, 4, 4, 4, 4, 4, 7, 4, 4, 4, 4, 4, 4, 4, 7, 4, // B0 .. BF
			5, 10, 10, 10, 10, 11, 8, 11, 5, 10, 10, 4, 10, 17, 8, 11, // C0 .. CF
			5, 10, 10, 8, 10, 11, 8, 11, 5, 4, 10, 8, 10, 4, 8, 11, // D0 .. DF
			5, 10, 10, 19, 10, 11, 8, 11, 5, 4, 10, 4, 10, 4, 8, 11, // E0 .. EF
			5, 10, 10, 4, 10, 11, 8, 11, 5, 6, 10, 4, 10, 4, 8, 11 // F0 .. FF
	};

	// This table contains timings for instructions ED 40 through ED 7F,
	// followed ED A0 through ED A3, ED A8 through ED AB, ED B0 through ED B3
	// and ED B8 through ED BB
	// Each time is adjusted by 4 T-States since the first 4 T-States are the time
	// for the initial ED opcode fetch/execute
	public static final byte[] Z80_TIME_PRE_ED = { 4, 4, 11, 16, 4, 10, 4, 5, 4, 4, 11, 16, 4, 10, 4, 5, // 40 .. 4F
			4, 4, 11, 16, 4, 10, 4, 5, 4, 4, 11, 16, 4, 10, 4, 5, // 50 .. 5F
			4, 4, 11, 16, 4, 10, 4, 14, 4, 4, 11, 16, 4, 10, 4, 14, // 60 .. 6F
			4, 4, 11, 16, 4, 10, 4, 4, 4, 4, 11, 16, 4, 10, 4, 4, // 70 .. 7F

			12, 12, 12, 12, // A0 .. A3
			12, 12, 12, 12, // A8 .. AB
			12, 12, 12, 12, // B0 .. B3
			12, 12, 12, 12 // B8 .. BB
	};

	protected static final int CYCLES_EXTRA_JRCC = 0;
	protected static final int CYCLES_EXTRA_DJNZ = 1;
	protected static final int CYCLES_EXTRA_CALLCC = 2;
	protected static final int CYCLES_EXTRA_RETCC = 3;
	protected static final int CYCLES_EXTRA_LDIR = 4;
	protected static final int CYCLES_EXTRA_CPIR = 5;
	protected static final int CYCLES_EXTRA_INIR = 6;
	protected static final int CYCLES_EXTRA_OTIR = 7;
	protected static final int CYCLES_EXTRA_IDXNORM = 8;
	protected static final int CYCLES_EXTRA_IDXLDIN = 9;
	protected static final int CYCLES_EXTRA_IDXCB = 10;
	protected static final int CYCLES_EXTRA_IM0 = 11;
	protected static final int CYCLES_EXTRA_IM1 = 12;
	protected static final int CYCLES_EXTRA_IM2 = 13;
	protected static final int CYCLES_EXTRA_INTACK = 14;

	protected static final byte[] Z80_TIME_EXTRA = { 5, 5, 7, 6, 5, 5, 5, 5, 8, 5, 4, 0, 0, 17, 2 };

	// Standard registers
	public static final int B = 0;
	public static final int C = 1;
	public static final int D = 2;
	public static final int E = 3;
	public static final int H = 4;
	public static final int L = 5;
	public static final int F = 6;
	public static final int A = 7;

	// Alternate register set
	public static final int B1 = 8;
	public static final int C1 = 9;
	public static final int D1 = 10;
	public static final int E1 = 11;
	public static final int H1 = 12;
	public static final int L1 = 13;
	public static final int F1 = 14;
	public static final int A1 = 15;

	// Declarations for get/setWordReg function
	public static final int BC = 0;
	public static final int DE = 2;
	public static final int HL = 4;
	public static final int AF = 6;

	// Flags
	public static final int FS = 0x80;
	public static final int FZ = 0x40;
	public static final int F5 = 0x20;
	public static final int FH = 0x10;
	public static final int F3 = 0x08;
	public static final int FPV = 0x04;
	public static final int FN = 0x02;
	public static final int FC = 0x01;

	protected static final int FLAG_MASK_LDIR = 0xe9;
	protected static final int FLAG_MASK_CPIR = 0xfa;
	protected static final int FLAG_MASK_CPL = 0xc5;
	protected static final int FLAG_MASK_CCF = 0xc5;
	protected static final int FLAG_MASK_SCF = 0xc5;
	protected static final int FLAG_MASK_ADDHL = 0xc4;
	protected static final int FLAG_MASK_RLCA = 0xc4;
	protected static final int FLAG_MASK_RLD = 0x01;
	protected static final int FLAG_MASK_BIT = 0x01;
	protected static final int FLAG_MASK_IN = 0x01;
	protected static final int FLAG_MASK_INI = 0xe8;

	// Register set
	protected int[] reg = new int[16];

	// 16-bit only registers
	protected int SP, PC, IX, IY;

	// 8-bit special registers
	protected int I, R, R7, IM;

	// Interrupt flip-flops
	protected boolean IFF1, IFF2;

	// No-Extra wait for CPC Interrupt?
	protected boolean noWait = false;

	// Currently executing a HALT instruction?
	protected boolean inHalt = false;

	// Flag to cause an interrupt to execute
	protected boolean interruptExecute = false;

	// Interrupt Vector
	protected int interruptVector = 0xff;

	// Pre-execute times
	protected byte[] timePre = new byte[256];

	// Post-execute times
	protected byte[] timePost = new byte[256];

	// CB code Pre-execute times
	protected byte[] timePreCB = new byte[256];

	// CB code Post-execute times
	protected byte[] timePostCB = new byte[256];

	// ED code Pre-execute times
	protected byte[] timePreED = new byte[128];

	// ED code Post-execute times
	protected byte[] timePostED = new byte[128];

	// Extra execute time for special or non-constant execution times
	protected byte[] timeExtra = new byte[2];

	private volatile int requestJp = -1;

	// Parity values
	protected static int[] PARITY = new int[256];
	static {
		for (int i = 0; i < 256; i++) {
			int p = (i & 0x01) == 0 ? FPV : 0;
			if ((i & 0x02) != 0)
				p ^= FPV;
			if ((i & 0x04) != 0)
				p ^= FPV;
			if ((i & 0x08) != 0)
				p ^= FPV;
			if ((i & 0x10) != 0)
				p ^= FPV;
			if ((i & 0x20) != 0)
				p ^= FPV;
			if ((i & 0x40) != 0)
				p ^= FPV;
			if ((i & 0x80) != 0)
				p ^= FPV;
			PARITY[i] = p;
		}
	};

	public Z80(long cyclesPerSecond) {
		super("Zilog Z80", cyclesPerSecond);
		setTimes();
	}
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

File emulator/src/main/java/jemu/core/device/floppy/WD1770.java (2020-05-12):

/*
 * WD1770.java
 *
 * Created on 27 July 2006, 20:45
 *
 * To change this template, choose Tools | Template Manager
 * and open the template in the editor.
 */

package jemu.core.device.floppy;

import jemu.core.*;
import jemu.core.cpu.*;
import jemu.core.device.*;

/**
 * This file is part of JemuVz200, an enhanced VZ200 emulator,
 * based on the works of Richard Wilson (2002) - see http://jemu.winape.net
 * <p>
 * The software is open source by the conditions of the GNU General Public Licence 3.0. See the copy of the GPL 3.0
 * (gpl-3.0.txt) you received with this software.
 *
 * @author Christian Wahlmann
 */

public class WD1770 extends Device {
  
  public static final int MOTOR_ON_DELAY   =  500000;
  public static final int MOTOR_OFF_DELAY  = 1500000;
  
  public static final int MOTOR_ON      = 0x80;
  public static final int WRITE_PROTECT = 0x40;
  public static final int SPIN_UP       = 0x20;
  public static final int DELETED_DATA  = 0x20;
  public static final int NOT_FOUND     = 0x10;
  public static final int CRC_ERROR     = 0x08;
  public static final int TRACK_ZERO    = 0x04;
  public static final int LOST_DATA     = 0x04;
  public static final int INDEX         = 0x02;
  public static final int DATA_REQUEST  = 0x02;
  public static final int BUSY          = 0x01;
  
  public static final int NO_COMMAND    = 0;
  public static final int EXECUTE       = 1;
  public static final int SETTLE        = 2;
  public static final int SPIN_DOWN     = 3;
  
  protected int status;
  protected int track;
  protected int sector;
  protected int data;
  
  protected int command;             // Current command
  protected int count;               // Current count
  protected int count2;              // Next count
  protected int count3;              // Third count
  protected int mode = NO_COMMAND;
  protected int currentTrack = 0;
  protected int direction = -1;
  protected int stepRate;
  protected int[] stepRates = { 6000, 12000, 20000, 30000 };
  protected int settleTime = 30000;
  
  protected Device interruptDevice;
  protected int interruptMask;
  protected Device dataRequestDevice;
  protected int dataRequestMask;
  
  /** Creates a new instance of WD1770 */
  public WD1770() {
    super("WD1770 Floppy Controller");
  }
  
  public void setInterruptDevice(Device device, int mask) {
    interruptDevice = device;
    interruptMask = mask;
  }
  
  public void setDataRequestDevice(Device device, int mask) {
    dataRequestDevice = device;
    dataRequestMask = mask;
  }
  
  protected void interrupt(boolean set) {
    if (interruptDevice != null) {
      if (set)
        interruptDevice.setInterrupt(interruptMask);
      else
        interruptDevice.clearInterrupt(interruptMask);
    }
  }
  
  protected void dataRequest(boolean set) {
    if (dataRequestDevice != null) {
      if (set)
        dataRequestDevice.setInterrupt(dataRequestMask);
      else
        dataRequestDevice.clearInterrupt(dataRequestMask);
    }
  }
  
  protected void spinup(int command) {
    status &= ~SPIN_UP;
    if ((command & 0x08) == 0 && (status & MOTOR_ON) == 0) {
      count = MOTOR_ON_DELAY;
      mode = SPIN_UP;
    }
    else
      mode = EXECUTE;
  }
  
  protected void seek(int command, int track) {
    System.out.println("Seek: " + track + ", current=" + currentTrack);
    spinup(command);
    stepRate = stepRates[command & 0x03];
    int diff = currentTrack - track;
    count2 = (diff < 0 ? -diff : diff) * stepRate;
    if (track < 0) currentTrack = 0;
    else if (track > 255) currentTrack = 255;
    else currentTrack = track;
    if ((command & 0x04) != 0)
      count2 += settleTime;
  }
  
  public int readPort(int port) {
    //System.out.println("FDC Read Port: " + port + ", status=" + Util.hex((byte)status));
    switch(port) {
      case 0: interrupt(false); return status;
      case 1: return track;
      case 2: return sector;
      case 3: dataRequest(false); return data;
    }
    return 0xff;
  }
  
  public void writePort(int port, int value) {
    System.out.println("FDC: Write port: " + port + " = " + Util.hex((byte)value));
    switch(port) {
      case 0: if ((status & BUSY) == 0 || (value & 0xf0) == 0xd0) command(value); break;
      case 1: if ((status & BUSY) == 0) track = value;                            break;
      case 2: if ((status & BUSY) == 0) sector = value;                           break;
      case 3: break;  // Data write
    }
  }
  
  protected void command(int value) {
    System.out.println("FDC Command: " + Util.hex((byte)value));
    command = value;
    status |= BUSY;
    switch(command & 0xf0) {
      case 0x00: seek(command,0);                                break; // Restore
      case 0x10: seek(command,data);                             break; // Seek
      case 0x20:
      case 0x30: seek(command,currentTrack + direction);         break; // Step
      case 0x40:
      case 0x50: direction = 1; seek(command,currentTrack +
                   (currentTrack > 76 ? -1 : 1));                break; // Step out
      case 0x60: 
      case 0x70: direction = -1; seek(command,currentTrack - 1); break; // Step in
    }
    if (mode == EXECUTE) {
      count = count2;
      count2 = 0;
    }
    System.out.println("Command started: mode=" + mode + ", count=" + count + ", count2=" + count2 +
      ", status=" + Util.hex((byte)status));
    ((Processor)interruptDevice).stop();
  }
  
  public void reset() {
    status = track = sector = data = 0;
  }
  
  public void cycle() {
    if (mode != NO_COMMAND && --count == 0) {
      System.out.println("Count done, mode=" + mode + ", status=" + Util.hex((byte)status));
      if (mode == SPIN_UP) {
        mode = EXECUTE;
        status |= SPIN_UP | MOTOR_ON;
        count = count2;
        count2 = 0;
      }
      else if (mode == EXECUTE) {
        status &= ~BUSY;
        if (command < 0x80) {
          if (currentTrack == 0) status &= ~TRACK_ZERO; else status |= TRACK_ZERO;
          if (command < 0x30 || (command < 0x80 && (command & 0x08) != 0))
            track = currentTrack;
        }
        interrupt(true);
        mode = SPIN_DOWN;
        count = MOTOR_OFF_DELAY;
      }
      else if (mode == SPIN_DOWN) {
        mode = NO_COMMAND;
        status &= ~MOTOR_ON;
      }
      System.out.println("New Mode: " + mode + ", count=" + count + ", status=" + Util.hex((byte)status));
    }
  }
  
}

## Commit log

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2019-05-13 Druckdaten (STL und GCode) Cura-Projekte
    [CE3_VZ200_Gehause oben_Kuhlrippen.3mf, VZ200_Gehäuse oben_Kühlrippen50Percent.stl, VZ200_Gehäuse unten_Kühlrippen.stl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]
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2019-05-18 Original Benutzerhandbuch VZ200 (deutsch), halloWelt2.asm Grafik-Assembler-Demo, superstartrek.bas (hat leider noch Fehler), Bilder eines Retro-Fernsehers von 1983, KICad-Doko
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2019-05-19 Tastatur Platinenlayout in 70 %, 1. Versuch
    [vz200-keyboard-layout.kicad_pcb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]
2019-05-20 emulator: fix another bug in Assembler; HalloWelt2 ist nun ein springender Ball ;-)
2019-05-23 emulator: VZ_CODEC korrigiert; Assembler: Test für Register implementiert
2019-05-23 Layout Keyboard Platine finalisiert
    [vz200-keyboard-layout-B.Cu.gbr, vz200-keyboard-layout-B.Mask.gbr, vz200-keyboard-layout-Edge.Cuts.gbr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]
2019-05-23 Old TV 3d-Object
    [set.obj]
2019-05-25 Folie für Tastaturschablone; Ober- und Unterteil nun mit Stutzen für Schrauben
    [vz200 v2.f3d]
2019-05-27 Oberteil geteilt und mit Anpass-Kante versehen
    [vz200 v2.1 v3.f3d]
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2019-05-30 Neue Druckdaten nach Modell V 2.1 Build 3
    [CE3_Tastaturschablone70Prozent.3mf, CE3_VZ200_Gehause oben_hinten_70Prozent.3mf, CE3_VZ200_Gehause oben_vorn_70Prozent.3mf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]
2019-05-30 Issue #19: Wandstärke der Schrauben-Stutzen vergrößert; in Boden nachträglich einzufügende Leisten mit Fixierhilfe versehen
2019-06-09 Neues Gehäusemodell druckfertig
    70% Größe, 0,2mm Schichtdicke
    [CE3_Tastaturschablone70Prozent.3mf, CE3_VZ200_Gehause oben_Kuhlrippen.3mf, CE3_VZ200_Gehause oben_hinten_70Prozent.3mf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]
2019-06-11 issue#21: Stutzen für Platinen-Schrauben erstellt
    [vz200-keyboard-layout.kicad_pcb]
2019-06-12 Verbindungsleiste zwischen Oberteil vorne und hinten verbreitert; Schraubstutzen für Controller und Platine; Halterung für Tastaturschablone; Dummy-Schalter zum Einsetzen; Loch für Tastaturkabel; Int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
2019-06-19 V4 Druckbereit gemacht
    [CE3_VZ200_Gehause oben_hinten_70Prozent.3mf, CE3_VZ200_Gehause oben_vorn_70Prozent.3mf, CE3_VZ200_Gehause unten_70%.3mf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]
2019-06-19 Gehäuse oben vorn Aussparungen an Schraubensockeln Neue Druckdaten für Gehäuse, Tastaturschablone und Schalter
    [CE3_Tastaturschablone70Prozent.3mf, CE3_VZ200_Schalter70%.3mf, VZ200_Gehäuse oben vorn_70%.stl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]
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2019-06-20 Modell: erste Version eines Monitors
    [Monitor v1.f3d]
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2019-06-20 Schablone ohne glattbügeln drucken
    [CE3_Tastaturschablone70Prozent.3mf]
2019-06-20 Monitor: Füße in richtige Position gebracht; Einschub für Powerbank hinzugefügt
    [Monitor v1.f3d]
2019-06-20 Monitor: Einschub Powerbank entfernt, dafür Lücke für Stromanschluss direkt am TFT (funktioniert besser und man kann zwischen Netzanschluss und Powerbank wählen)
    [Monitor v1.f3d]
2019-06-24 Monitor Version mit Schraubstutzen; Screenshots Tastaturmatte lackiert
    [Monitor v2.f3d]
2019-06-24 Monitor: Füße als einzelne Objekte abgetrennt; Öffnung für Raspi-Ports 1mm nach außen verschoben
    [Monitor v2.f3d]
2019-06-30 Tastatur in TPU und Holz Aktuelle Versionen von VZ200 und Monitor
    [CE3_Fuß.3mf, CE3_Monitor-Gehause-hinten.3mf, CE3_Monitor-Gehause-vorn.3mf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]
2019-06-30 emulator: Rand außerhalb des Bildschirms vergrößert, damit durch Monitorgehäuse keine Zeichen abgeschnitten sind; Rendern der Grafikzeichen gefixt (Bits wurden falsch ausgewertet)
2019-07-01 emulator: add reset-key (F7); make devices reset, when CPU resets; add in-emulator alert when using custom out / in ports for vz-progs and tape-control; implement reset-method for tape-device
2019-07-01 tastatur /emulator: Reset-Taste (ESC) implementiert; Platinenlayout ergänzt und beschriftet
    [vz200-keyboard-layout.kicad_pcb, vz200-keyboard-layout.sch]
2019-07-06 Issue 38 Gehäuse angepasst (ohne Tastatur) Neue Druckdaten
    [CE3_VZ200_Gehause oben_hinten_70Prozent.3mf, CE3_VZ200_Gehause unten_70%.3mf, VZ200_Gehäuse oben hinten_70%.stl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]
2019-07-10 3d-modell: Monitor v2.0 finalisiert: mehr Spiel für Schraubstutzen; Lautsprecher eingepasst mit Halterung und Schlitzen; Halterung für Verstärkerplatine; Lüftungsschlitze; Front im Retro-Look
    [Monitor v2.f3d]
2019-07-11 Neue Druckdaten
    [CE3_Monitor-Gehause-hinten.3mf, CE3_Monitor-Gehause-vorn.3mf, Monitor-Gehäuse-hinten.stl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]
2019-07-13 Monitor: Lautsprecherhalterung enger
    [Monitor v2.f3d]
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2019-07-22 Emulator: Volume-Control des Java SoundSystems ist im Raspberry nicht verfügbar. Deswegen Volume-Regelung bei der Tonerzeugung im Emulator (0-127); poke 28671,<vol> setzt auch die Lautstärke
2019-07-31 emulator: Erweiterung der Rest-Schnittstelle: optionaler autorun-Parameter für POST asm und GET vz; POST asm gibt nun Speicherbereich zurück; thehunter.asm als Minispiel
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2019-08-07 Korrekturen an Monitor und VZ-Gehäuse Resetschalter am VZ-Gehäuse Tastaturschablone mit Haken Neue Druckdaten
    [CE3_Monitor-Fuß-vorne.3mf, CE3_Tastaturschablone70Prozent.3mf, CE3_VZ200_Gehause oben_hinten_70Prozent.3mf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]
2019-08-16 Unterseite Gehäuse aktualisiert
    [CE3_VZ200_Gehause unten_70%.3mf]
2019-08-16 Emulator: fix a bug when the VZ is reset; fix the loadAsm-Routine: stop the processor before loading and start it when finished.
    [Z80.java]
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2019-09-08 Resetschalter Klemme Monitor neue Druckdaten
    [CE3_Monitor-Gehause-vorn.3mf]
2019-09-08 Repo bereinigen
    [Monitor v1.f3d, Monitor v2.f3d, Monitor v4 v5.f3d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]
2019-09-12 Erster RESTservice implementiert (Reset)
    [CE3_PocketMetricScrewSizer_black.3mf]
2019-09-14 Emulator: fix disassembler output and assembler comment handling
2019-09-15 Emulator: Erweiterung des REST-Interface: mit /vz200/asmzip können Zip-Dateien geladen werden, die mehrere Asm-Source-Artefakte enthalten. Beispiel siehe halloWelt.zip
2019-09-17 3D-Modell: Texturen für Tastaturschablone und Tasten auf Flächen angebracht; Bilder neu gerendert
2019-09-23 Neue Druckdaten Gehäuse unten Lautstärkeregler (in Arbeit)
    [CE3_VZ200_Gehause unten_70%.3mf, VZ200_Gehäuse unten_70%.stl]
2019-09-29 VZ (extends Computer) als SpringBean eingebunden; Audio-Volume-Control nutzt jetzt die Controls von Java Sound, normalisiert auf Werte [0..255]; Volume-Control von Basic aus: in/out Port 251; Beispie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
2019-09-29 Gehäuse hinten Anpassungen (in Arbeit) App - Lautstärke per Regler einstellen in 16 Schritten
    [VZ200_Gehäuse oben hinten_70%.stl, VZ200_Gehäuse oben vorn_70%.stl]
2019-09-30 Schaltplan Audio
    [audio-verstaerker.kicad_pcb, audio-verstaerker.sch]
2019-10-03 Restclient: POST volume returns "OK."; new request to get registers; Processor: main loop is paused during reset to disable side-effects during reset
    [Z80.java]
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2019-11-02 Gehäuse unten: Resetschalterhalterung um 5mm nach links versetzt Unterseite vorn geglättet für bessere Druckbarkeit Loch für USB-Kabel vergrößert Neue Druckdaten für VZ-Gehäuse
    [CE3_VZ200_Gehause oben_hinten_70Prozent.3mf, CE3_VZ200_Gehause oben_vorn_70Prozent.3mf, VZ200_Gehäuse oben hinten_70%.stl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]
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2020-01-31 Screenshots Monitor Anleitung
    [vz200-keyboard-layout.kicad_pcb]
2020-01-31 execute soft reset in cpu thread to avoid deadlocks
    [Z80.java]
2020-02-01 Fix bug in reset routine that causes a delay in sound; remove redundant reset of interruptPending flag (is called in Processor.reset())
    [Z80.java]
2020-02-05 Service um weitere Methoden erweitert
    [VZ200_Gehäuse unten_signatur_100%.stl]
2020-02-08 Bugfix in Z80 CPU Emulator beim Decrement; Programmierbeispiele (Assembler in Basic laden und nutzen)
    [Z80.java]
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2020-02-17 Dokumentation erweitert
    [VZ200-Basic.ods]
2020-02-19 3D-Modell korrigiert auf die vorletzte Version (die letzte Version hatte den Boden auf 70% verkleinert)
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2020-03-02 Neuer VZ-Anhänger 3D-Druckdaten für Tastaturmatte aktualisiert
    [CE3_VZ200 15% Anhanger.3mf, CE3_VZ200_Tastatur Tasten_5.5_70%.3mf, VZ200 10% Anhänger.stl]
2020-03-15 #71: PC (program-counter)-Änderungen werden nun immer vom Prozessor-Thread selbst durchgeführt; REST-Methode keyboardType cached nun Eingaben und führt sie asynchron durch; unterstützt nun Json; Rese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
    [Z80.java]
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2020-06-01 #91: switch to swagger 3, wich is supported natively be spring boot; fix bug in security device (unused); switch from shadow-jar to boot-jar build; swagger-ui now available at /api/swagger
2020-09-27 #102: add australian graphics mod; add configuration to enable; add configuration to enable 16k RAM expansion; fix basic cheat sheet; add two hires basic examples
    [VZ200-Basic.ods]
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2021-01-04 #104: Device-Scanner; Editor-Theme; Dark/Light-Theme; Banner; App-Icon; Fix some bugs
2021-01-09 #104: implement printer and tapedeck pages; fix Jemu-Rest-controller
2021-01-09 #104: fix returned error message in assembler
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
